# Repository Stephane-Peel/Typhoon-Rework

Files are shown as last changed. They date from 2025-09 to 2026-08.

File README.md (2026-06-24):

# Typhoon
Clouds variant

Fork to share production files used to make mine.

- Frontpanel rework to my taste.
- Kicad conversion from Diptrace
- 3D CAD : Fusion 360 & STL
- Original Fuzzy BOM reference completed

Beware : 
--------
The current files where used for my build.
It should be ok, but please double check everything to make your own module ;)

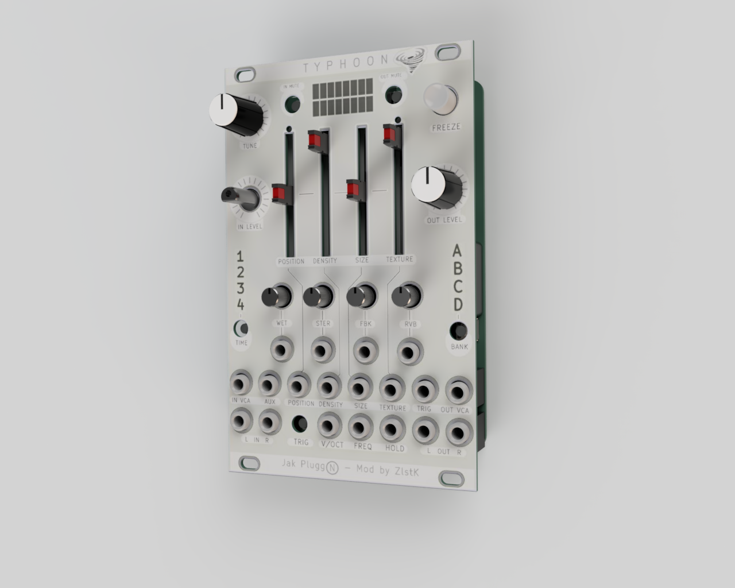
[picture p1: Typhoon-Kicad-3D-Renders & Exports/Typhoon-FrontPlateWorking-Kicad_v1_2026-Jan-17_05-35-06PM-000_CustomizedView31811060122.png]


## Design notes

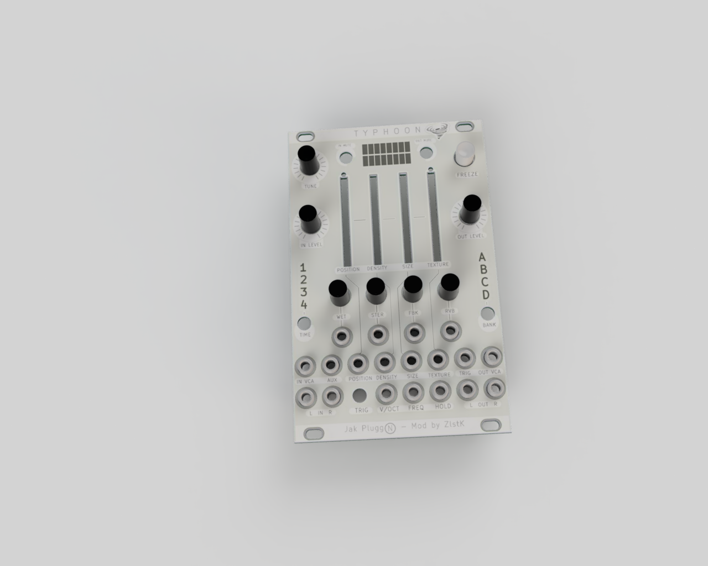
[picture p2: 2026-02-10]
Typhoon-Kicad-3D-Renders & Exports/33a217c0-9740-4eda-9ab5-972cdd618269.PNG

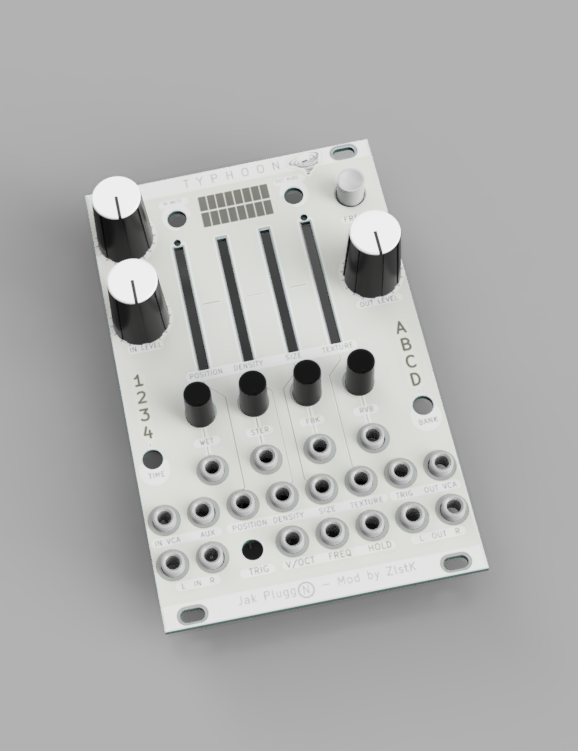
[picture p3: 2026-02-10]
Typhoon-Kicad-3D-Renders & Exports/Typhoon-FrontPlateWorking-Kicad_v1_2026-Jan-16_11-33-02PM-000_CustomizedView1730624913.png

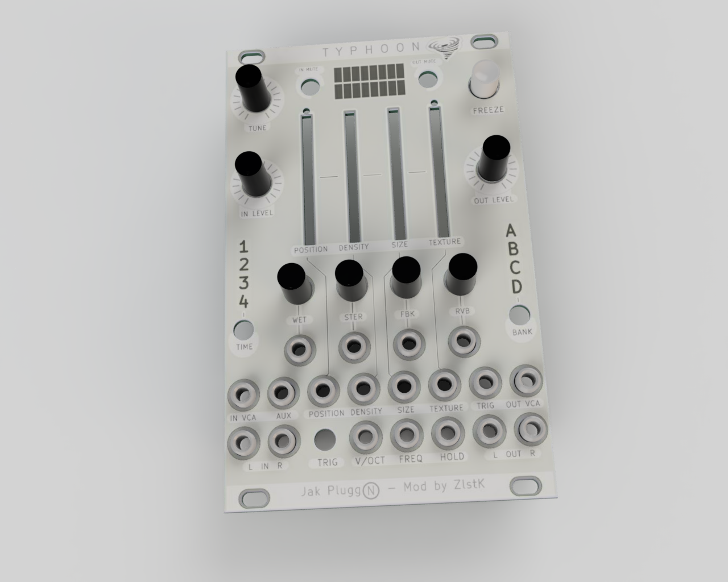
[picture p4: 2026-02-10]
Typhoon-Kicad-3D-Renders & Exports/Typhoon-FrontPlateWorking-Kicad_v1_2026-Jan-16_11-52-13PM-000_CustomizedView21636484477.png

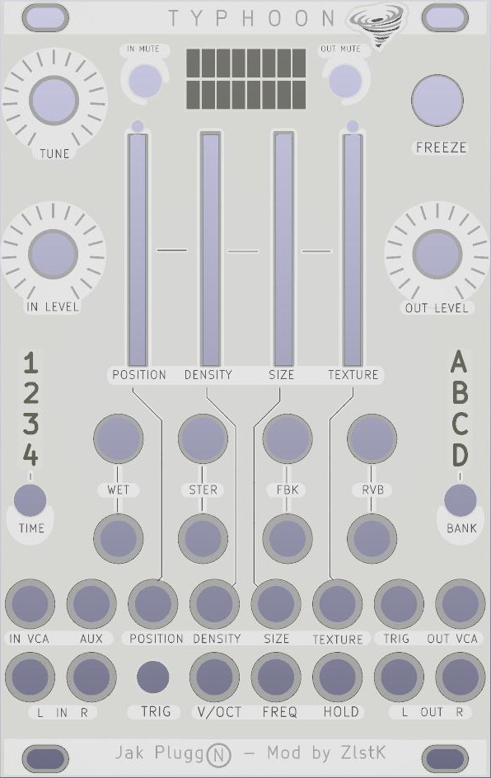
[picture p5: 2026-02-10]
Typhoon-Kicad-3D-Renders & Exports/Typhoon-Frontpanel-LargeKnobs.jpg

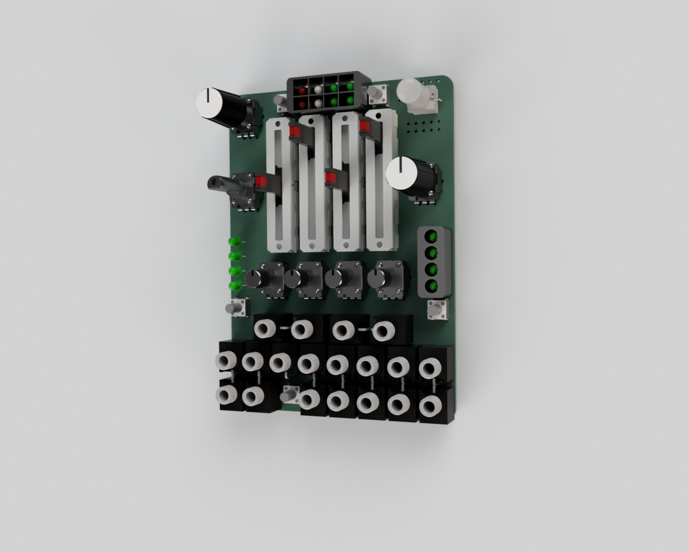
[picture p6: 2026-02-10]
Typhoon-Kicad-3D-Renders & Exports/Typhoon-FrontPlateWorking-Kicad_v1_2026-Jan-17_05-37-42PM-000_CustomizedView23703180181.png

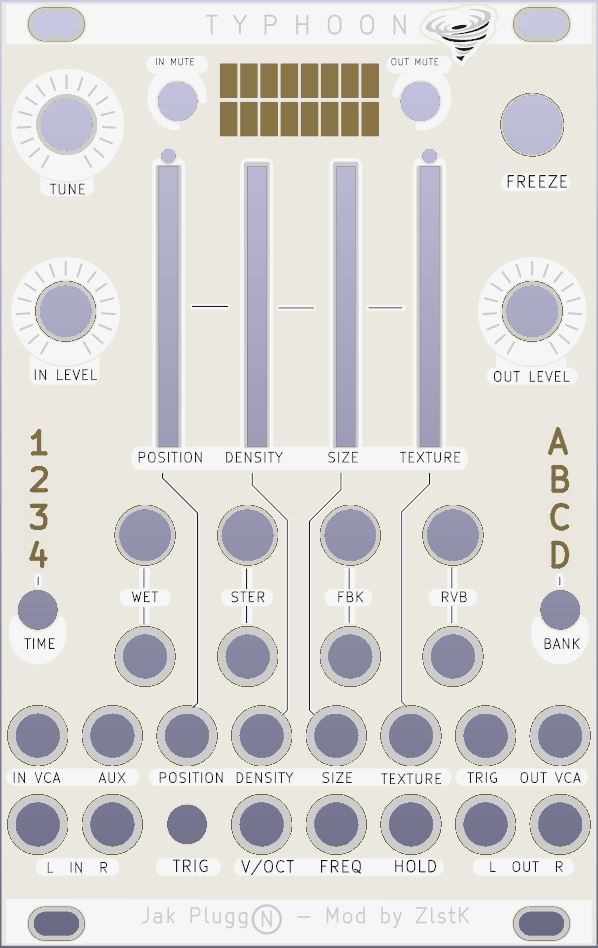
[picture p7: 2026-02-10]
Typhoon-Kicad-3D-Renders & Exports/FrontplateV1.1.JPG

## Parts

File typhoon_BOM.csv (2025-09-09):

Quantity | Value | Name | RefDes
2 | 2.2UF | C-EUC0603 (C-EU) | C1, C8
4 | 18PF | C-EUC0603 (C-EU) | C2, C3, C42, C43
7 | 10UF | C-EU-POL_4D (C-EU-POL) | C4, C17, C19, C20, C28, C29, C30
33 | 100NF | C-EUC0603 (C-EU) | C5, C6, C7, C11, C13, C15, C16, C18, C21, C22, C23, C26, C31, C32, C33, C37, C40, C44, C48, C51, C53, C55, C56, C61, C62, C63, C66, C70, C71, C72, C73, C75, C78
6 | 47PF | C-EUC0603 (C-EU) | C9, C12, C24, C25, C64, C65
2 | 220PF | C-EUC0603 (C-EU) | C10, C14
4 | 10UF | C-EUC0805 (C-EU) | C27, C35, C36, C50
8 | 560PF | C-EUC0603 (C-EU) | C34, C39, C45, C46, C47, C49, C52, C54
2 | 470NF | C-EUC0603 (C-EU) | C38, C41
9 | 10NF | C-EUC0603 (C-EU) | C57, C58, C59, C60, C67, C68, C69, C74, C76
1 | 1NF | C-EUC0603 (C-EU) | C77
1 |  | MB1S | D1
2 | FB | FERRITE_BEAD_0603 (FERRITE_BEAD) | FB1, FB2
3 | Eurorack Jack | EURO_JACKS_SMALL_SILK (EURO_JACK) | J_AUX, J_HOLD, J_TRIG
16 | Eurorack Jack | EURO_JACKS_SILK (EURO_JACK) | J_DENS, J_FDBK, J_I-LVL, J_LIN, J_LOUT, J_MIX, J_O-LVL, J_PAN, J_PITCH, J_POSI, J_RIN, J_ROUT, J_SIZE, J_TEXT, J_VERB, J_VOCT
1 |  | M04PTH | JP1
10 | 2mm Yellow Diffused | LED_SILK (LED) | LED_A, LED_B, LED_C, LED_D, LED_IN3, LED_OUT3, LED_T1, LED_T2, LED_T3, LED_T4
4 | 2mm Green Diffused | LED_SILK (LED) | LED_IN1, LED_IN2, LED_OUT1, LED_OUT2
2 | 2mm Red Diffused | LED_SILK (LED) | LED_IN4, LED_OUT4
1 | M05X2PTH | M05X2PTH | P1
1 | Mini JTAG Header | M05X2MINIJTAG (M05X2) | P2
1 | 12.288MHz | TXC 7A crystal | Q1
1 | 8MHz | TXC 7A crystal | Q2
2 | MMBT3904 | -NPN-MMBT3904LT1SOT23-BEC (*-NPN-) | Q3, Q4
5 | 100R | R-US_R0603 (R-US_) | R1, R2, R7, R8, R75
18 | 1K | R-US_R0603 (R-US_) | R3, R4, R5, R6, R39, R42, R44, R46, R47, R48, R49, R50, R90, R91, R98, R99, R100, R101
2 | 2K | R-US_R0603 (R-US_) | R9, R11
6 | 10K | R-US_R0603 (R-US_) | R10, R13, R14, R16, R17, R21
2 | 5K1 | R-US_R0603 (R-US_) | R12, R15
5 | 22K | R-US_R0603 (R-US_) | R18, R20, R29, R30, R34
10 | 510R | R-US_R0603 (R-US_) | R19, R22, R23, R26, R27, R32, R33, R35, R37, R67
3 | 1M | R-US_R0603 (R-US_) | R24, R41, R71
2 | 39K | R-US_R0603 (R-US_) | R25, R31
2 | 49K9 | R-US_R0603 (R-US_) | R28, R36
23 | 100K | R-US_R0603 (R-US_) | R38, R40, R43, R45, R51, R52, R61, R62, R63, R64, R65, R66, R68, R70, R73, R74, R82, R86, R87, R92, R93, R95, R97
12 | 200K | R-US_R0603 (R-US_) | R53, R55, R56, R57, R69, R72, R76, R77, R78, R83, R85, R94
9 | 33K | R-US_R0603 (R-US_) | R54, R58, R59, R60, R79, R80, R81, R84, R88
1 | 180K | R-US_R0603 (R-US_) | R89
1 | 47K | R-US_R0603 (R-US_) | R96
5 | Mini Button | TAC_SWITCHTACTILE_PTH_SILK (TAC_SWITCH) | S_BANK, S_MUTE_INS, S_MUTE_OUTS, S_TIME, S_TRIG
1 | LED Button White | LED_BUTTONLED_BUTTON_SILK (LED_BUTTON) | S_HOLD
1 | STM32F427VIT6 | STM32F4XXV2 | U1
1 |  | WM8731 | U2
2 | TL074 | TL074_SO-14 (TL074) | U3, U16
2 | LD1117-3V3 | LD1117-3V3 (LD1117) | U4, U10
2 | 2164 | SSI2164 | U5, U9
1 | LM4040-2V5 | LM4041DBZA12 (LM4041) | U6
2 | LM4040-10V | LM4041DBZA12 (LM4041) | U7, U13
1 | 4051 | 4051_MUX | U8
5 |  | MCP6002 | U11, U12, U15, U17, U18
1 | TL072 | TL072_SO-8 (TL072) | U14
2 |  | TLE2172 | U19, U20
4 |  | bourns PTL LED slide pot | VR_DENS, VR_POSI, VR_SIZE, VR_TEXT
7 | P-10K-B | POT_9MM_SNAP-IN__ (POT_9MM_SNAP-IN_) | VR_FDBK, VR_IN, VR_MIX, VR_OUT, VR_PAN, VR_PITCH, VR_VERB

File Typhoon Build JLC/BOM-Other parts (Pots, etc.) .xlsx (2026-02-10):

Comment | Designator | Ref. | Quantity | Comment
Eurorack Jack | J_DENS, J_FDBK, J_I-LVL, J_LIN, J_LOUT, J_MIX, J_O-LVL, J_PAN, J_PITCH, J_POSI, J_RIN, J_ROUT, J_SIZE, J_TEXT, J_VERB, J_VOCT, J_AUX, J_HOLD, J_TRIG | Thonkiconn | 19 | Thonk : ok Ali : ok
Mini Button | S_BANK, S_MUTE_INS, S_MUTE_OUTS, S_TIME, S_TRIG | E-Switch - 1RLGR (depend on your choice) | 5 | Digikey : ok | https://www.digikey.fr/fr/products/detail/e-switch/1RLGR/271580
Tactile Switch |  | E-Switch - TL1105SPF160Q | 5 | Digikey : ok | https://www.digikey.fr/fr/products/detail/e-switch/TL1105SPF160Q/271558
LED Button White | S_HOLD | E-Switch - LP4OA1PBCTG | 1 | Banzai : ok Ali : ok | https://www.digikey.fr/fr/products/detail/e-switch/LP4OA1PBCTG/1984647
WM8731 | U2 |  |  | Ali : ok
AS2164 | U5, U9 | SO-16 | 2 | Exploding : ok Banzai : ok Thonk : x3 uniquement
 | VR_DENS, VR_POSI, VR_SIZE, VR_TEXT | Bourns - PTL30-10G1-103B2 | 4 | Digikey : ok | https://www.digikey.fr/fr/products/detail/bourns-inc/PTL30-10G1-103B2/4699464
P-10K-B | VR_FDBK, VR_IN, VR_MIX, VR_OUT, VR_PAN, VR_PITCH, VR_VERB | Alps - RK09K1130A5R | 4 | Digikey : ok | https://www.digikey.fr/fr/products/detail/alps-alpine/RK09K1130A5R/21721633
B10K |  | Alps - RK09D1130C2P | 3 | Digikey : ok | https://www.digikey.fr/fr/products/detail/alps-alpine/RK09D1130C2P/19529056
Led Slider | Bicolor LEDs for PTL30 | Bivar - R3BC | 4 | Digikey : ok | https://www.digikey.fr/fr/products/detail/bivar-inc/R3BC/3101096
Front-Panel Screw | 2,5mm x10 |  | 2
Pot Caps | Pots Caps |  | 3

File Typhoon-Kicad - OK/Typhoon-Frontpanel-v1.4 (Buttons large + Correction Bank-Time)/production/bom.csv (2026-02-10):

Designator | Footprint | Quantity | Value | LCSC Part #
PAD1, PAD15, PAD16, PAD17, PAD18, PAD19, PAD2, PAD20, PAD3, PAD30, PAD31, PAD32, PAD33, PAD4, PAD5, PAD6, PAD7, PAD8, PAD9 | RES_0805_Pad1 | 19 | PAD
PAD10, PAD11, PAD13, PAD14 | Pad-Eurorack-Vis | 4 | PAD
PAD12 | RES_0805_Pad12 | 1 | PAD
PAD21, PAD22, PAD23, PAD24, PAD25, PAD26, PAD34 | RES_0805_Pad21 | 7 | PAD
UNK_HOLE_0 | dummyfp0 | 1
UNK_HOLE_1 | dummyfp1 | 1
UNK_HOLE_2 | dummyfp2 | 1
UNK_HOLE_3 | dummyfp3 | 1
UNK_HOLE_4 | dummyfp4 | 1
UNK_HOLE_5 | dummyfp5 | 1
UNK_HOLE_6 | dummyfp6 | 1

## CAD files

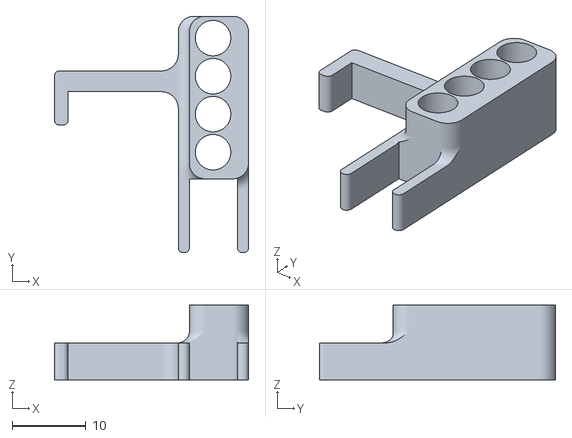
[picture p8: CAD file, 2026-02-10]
Typhoon - CAD Files/TyphoonGuide1234.stl
26.3 x 32.0 x 10.1

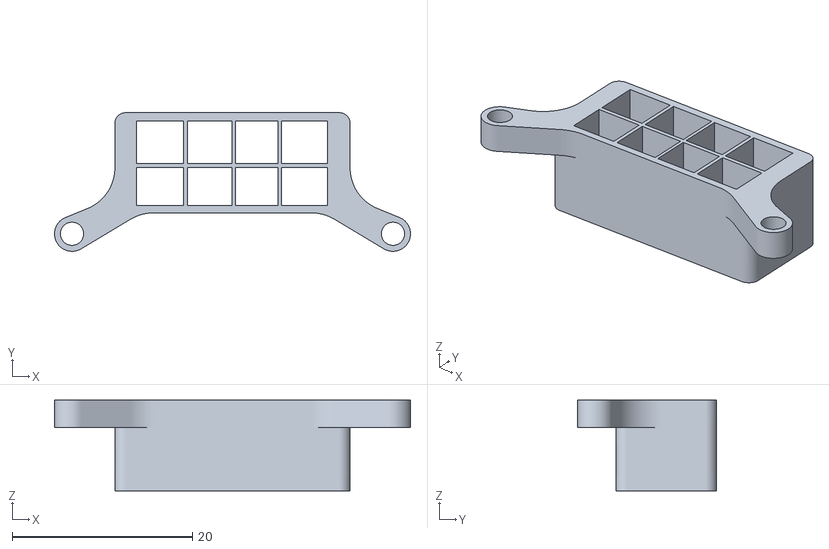
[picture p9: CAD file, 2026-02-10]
Typhoon - CAD Files/TyphoonGuideVueMeter.stl
39.5 x 15.4 x 10.1

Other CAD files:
Typhoon - CAD Files/TyphoonGuideABCD.stl
Typhoon - CAD Files/Typhoon-FrontPlateWorking-Kicad.f3z

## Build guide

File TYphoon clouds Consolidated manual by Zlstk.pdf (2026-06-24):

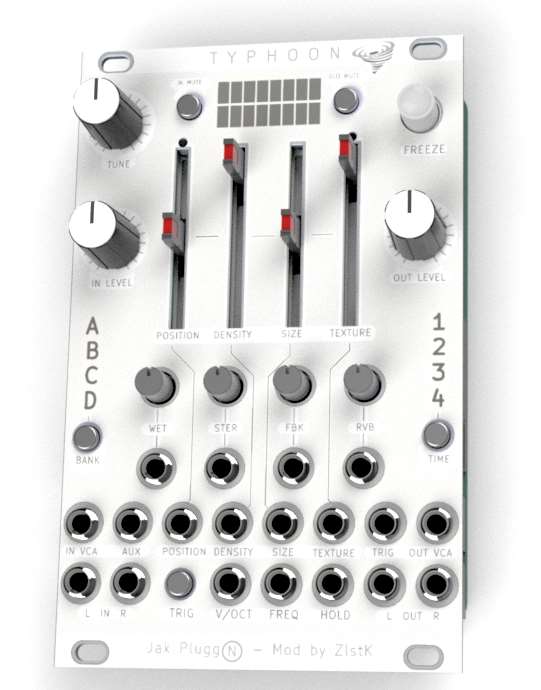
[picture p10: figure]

# TYphoon - Clouds

# Superparasite

# Consolidated Manual V 1.0

Typhoon Clouds – Superparasite Consolidated Manual V1.0 – By Zlstk

# Overview

This Document is a compilation of the documentation of these differents version of Clouds and the work of other people:

Original Clouds by Emilie Gillet : https://pichenettes.github.io/mutable-instruments-documentation/modules/clouds/manual/# (https://pichenettes.github.io/mutable-instruments-documentation/modules/clouds/manual/)

Supercell : https://grayscale.info/supercell/

Microcell : https://microcell.cc/

Capital-G : https://github.com/capital-G/typhoon-manual

Clouds is a granular audio processor. It creates textures and soundscapes by combining multiple overlapping, delayed, transposed and enveloped segments of sound taken from an audio recording buffer.

Clouds differs from other granular Eurorack modules in that it focuses on the real-time processing of audio sources from your modular system itself, rather than the playback of pre-recorded samples from a storage device. It rewards the freezing, fragmentation and dissolution of the unexpected instant, rather than the careful planning of what might very well not come.

(Source – Original Clouds Manual by Emilie Gillet)

Typhoon is an iteration of differents versions of the original Clouds module by Emilie Gillet.

Clouds ->Supercell -> Microcell Clouds -> µBurst -> Moonsoon -> TYPHOON

Typhoon offer extra controls and mods comparing to original Clouds.
It use the Superparasite firmware. (see https://github.com/patrickdowling/superparasites for more details).

Superparasite include all the regular Clouds modes, all the Parasites modes, and Kammerl Beat Repeat and Spectral Clouds modes.

Mode 1 [●○○○]: Granular Clouds (Parasites)
Mode 2 [○●○○]: Pitch Shift / Time Stretch (Parasites) Mode 3 [○○●○]: Looping Delay (Parasites)
Mode 4 [○○○●]: Spectral Processor (Parasites)
Mode 5 [○●●●]: Oliverb (Parasites)
Mode 6 [●○●●]: Resonestor (Parasites)
Mode 7 [●●○●]: Beat Repeat (Kammerl)
Mode 8 [●●●○]: Spectral Clouds (Kammerl)

# General Settings and functionnality

Microcell - Calibration Procedure:

1. Patch a cable from any DC offset source or MIDI-to-CV module into the V/OCT input (not the Pitch input).
2. Power on your modular system while holding the TRIG switch. The input VU meter will start to blink.
3. Send a 1V DC offset into the module. Many Eurorack modules can generate DC offsets but you will need some way to measure the voltage. Use a digital multimeter or an oscilloscope module like the Mordax DATA to generate precise values. Alternately, use your MIDI-to-CV module and play a C2 note. When the 1V signal is present at the V/OCT input, press the TRIG switch.
4. The output VU meter will now start to blink. Change the 1V DC offset to 3V instead (or play C4 on your MIDI-to-CV module), then press the TRIG switch once more. The calibration process will exit and the module will return to normal operation.

Supercell - Exponential and Linear Pitch Control

The PITCH parameter is now controlled by two separate CV inputs.
The V/OCT input is exponential and the Pitch input is linear (with an attenuverter). When both inputs are used, the two voltages are summed.

Supercell - Trigger Switch

Clouds had a trigger/gate input for generating individual grains.
Supercell adds a manual TRIG switch that performs the same function.
It’s particularly useful with some of the alternate firmware modes such as Beat Repeat.
This switch isalso used for the quick reload function and adjustment of the internal random voltage generator’s clock rate. See the notes above for details

Supercell - Expanded Modulation Options

Each of the nine granular processing parameters has its own CV input with an inverting attenuator (attenuverter) to set the level and polarity of external CVs.

Along with patching external CVs directly to each CV input, you may want one CV to affect multiple parameters without using splitter cables or a multiple module. Patch a CV signal into AUX and it will be distributed to all nine of the parameters.

The attenuverters can still be used to control the modulation depth of this distributed CV signal. Patching a different signal directly into one of the nine CV inputs will disconnect the AUX signal from that parameter.

Supercell - Internal Modulation

There is a third option for modulation, which involves a fluctuating random CV that is internally generated by the module itself. Any unpatched parameter inputs will receive this signal automatically (assuming that the AUX input is also unpatched, because patching into AUX overrides this internal random CV). The attenuverters control the modulation depth here as well.
> To prevent the internal modulation from changing a parameter, set the attenuator to its center position. > To change the frequency of the random CV changes. Press and hold the TRIG switch and then turn the PAN knob until the HOLD LED starts to blink. The randomization frequency will change when the TRIG switch hold is released. Return the Pan knob to its original position if needed.
>The available range is from 1 Hz to 100 Hz.
> To disable the internal random CV, press both of the mute switches for about two seconds. > When the modulation, is activated you can see a visual activity on the four slider pots of Typhoon

Microcell - attenuation feature :

- Press and hold the TIME switch, then turn a knob within 3 seconds (otherwise you enter the mode selection UI).
The knob now functions as an attenuator for that parameter's CV input.
The attenuation value is saved when you release the TIME switch hold.
Turning other knobs before releasing the switch hold will adjust their attenuation values too.
- Press and hold the BANK switch, then turn a knob within 3 seconds (otherwise you enter the preset saving UI).
This works as described above, but the knob functions an inverting attenuator.
With the knob turned to left of center incoming CVs with be attenuated *and* inverted, while values to the right of center will only be attenuated.
This function works for all nine of the DSP parameters.
It does not work for the analog Input and Output VCAs.

It does however mean that the internal randomization feature can be used more effectively.

Just enable the randomization (press and hold the In and Out mute switches for 5 seconds), then set the attenuation values.

Stereo Input/Output VCAs

The inputs and outputs now include stereo VCAs and separate VU meters. The knobs for Input and Output function as DC offsets for their respective VCAs, setting the modulation baseline when the VCA inputs are patched, so turn these knobs to their minima if you want to use unipolar CV sources like envelopes. CV signals affect the left and right channels equally. If you prefer to modulate the left and right channels separately, this can be accomplished with external VCAs.

# License

cc-by-sa 3.0

Mutable Instruments Manual: cc-by-sa 3.0

Kammerl: MIT License (https://www.kammerl.de/audio/clouds/NOTICE.txt)

Parasites: MIT LIcense (https://mqtthiqs.github.io/parasites/)

Superparasites: MIT License (https://github.com/patrickdowling/superparasites#license)

# Mode 1 [●○○○]: Granular Clouds (Parasites)

Source: mqtthiqs Parasites (https://mqtthiqs.github.io/parasites/clouds.html)

ORIGINAL
BUTTON

PARAMETER DESCRIPTION

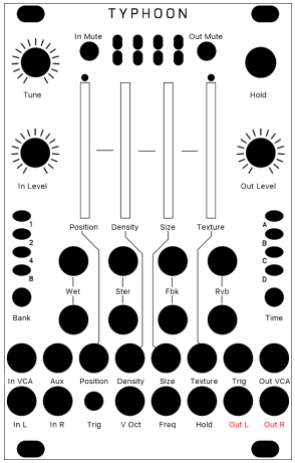
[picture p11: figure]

POSITION | Position | Selects from which part of the recording buffer the audio grains are
| | played. Turn the knob clockwise to travel back in time.
DENSITY | Density | At 12 o’clock, no grains are generated. Turn clockwise and grains will be
| | sown randomly, counter-clockwise and they will be played at a constant
| | rate. The further you turn, the higher the overlap between grains.
SIZE | Size | At 12 o’clock, the buffer is played at its original frequency.
TEXTURE | Texture | Morphs through various shapes of grain envelopes: square (boxcar),
| | triangle, and then Hann window. Past 2 o’clock, activates a diffuser which
| | smears transients.
WET | Wet | Dry/wet balance
STEREO | Stereo | Stereo spread (amount of random panning/balance applied to the grains).
FEEDBACK | Feedback | Feedback amount.
REVERB | Reverb | Reverberation amount.
FREEZE | Freeze | This latching button stops the recording of incoming audio.
| | Granularization is now performed on the last few seconds of audio kept
| | in memory in the module. When the input gate signal is high, stops the
| | recording of incoming audio, just as latching the FREEZE button would
| | do.
TRIGGER | Trigger | Generates a single grain. By moving the grain DENSITY to 12 o’clock, and
| | sending a trigger to this input, Clouds can be controlled like a micro-
| | sample player. An LFO or clock divider (or even a pressure plate) can thus
| | be used to sow grains at the rate of your choice.
INPUT LEVEL | In Level | From -18dB to +6dB.

# Mode 2 [○●○○]: Pitch Shift / Time Stretch (Parasites)

This mode is quite similar to the granular mode, except that it uses two overlapping grains synchronized with the most salient period of the sound. The grains are carefully spliced so that they mesh well with each other (a technique similar to the “deglitching” of early pitch-shifters).

Source: mqtthiqs Parasites (https://mqtthiqs.github.io/parasites/clouds.html)

ORIGINAL
BUTTON

PARAMETER DESCRIPTION

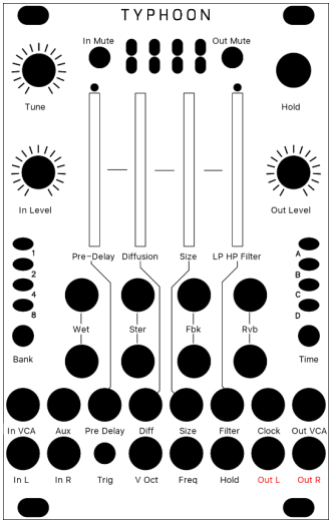
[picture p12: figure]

POSITION | Pre-Delay | Modulating POSITION when recording is frozen will “scrub” through the audio buffer. Clouds’ uses classic time-domain methods which are not suitable for polyphonic or percussive material (unless this percussive material is breakbeats and you liked Akai samplers. Then: smile).
DENSITY | Diffusion | Creates a granular diffusion effect based on all-pass filters.
SIZE | Size | Controls the size of the overlapping windows used for pitch-shifting and time-stretching – from an extremely grainy “drilling” sound to smooth bits of loops.
TEXTURE | LP/HP Filter | Acts as a low-pass/high-pass filter.
TRIGGER | Trigger | Sending a trigger to the TRIG input creates a clock-synchronized loop (when FREEZE is enabled) or stuttering effect – equivalent to applying a tempo-synchronized decaying envelope on the POSITION parameter.

# Mode 3 [○○●○]: Looping Delay (Parasites)

The looping delay mode continuously plays back audio from the buffer without any kind of granularization.

Source: mqtthiqs Parasites (https://mqtthiqs.github.io/parasites/clouds.html)

ORIGINAL
BUTTON

PARAMETER DESCRIPTION

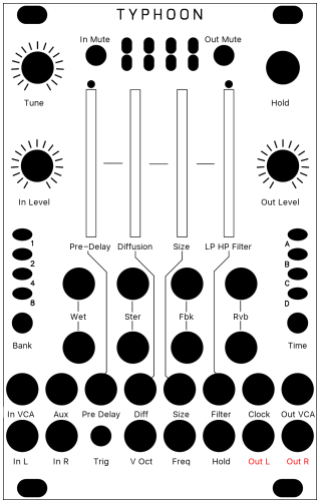
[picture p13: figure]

POSITION | Pre-Delay | Controls the distance between the playback head and the recording head (in other words, the delay time). Modulating POSITION will create effects similar to vinyl scratching or manual manipulation of tape.
DENSITY | Diffusion | Creates a granular diffusion effect based on all-pass filters.
SIZE | Size | Controls the size of the overlapping windows used for pitch-shifting and time-stretching – from an extremely grainy “drilling” sound to smooth bits of loops.
TEXTURE | LP/HP Filter | Acts as a low-pass/high-pass filter.
HOLD | Hold | When FREEZE is activated, the content of the audio buffer is looped (stutter effect). POSITION controls the loop start and SIZE the loop duration. DENSITY creates a granular diffusion effect based on all-pass filters; and TEXTURE acts as a low-pass/high-pass filter.

# Mode 4 [○○○●]: Spectral Processor (Parasites)

In this mode, the incoming signal is converted into “frames” of spectral data, that are stored, transformed, recombined, and resynthesized as a time-domain signal.

Source: mqtthiqs Parasites (https://mqtthiqs.github.io/parasites/clouds.html)

ORIGINAL
BUTTON
| PARAMETER | DESCRIPTION

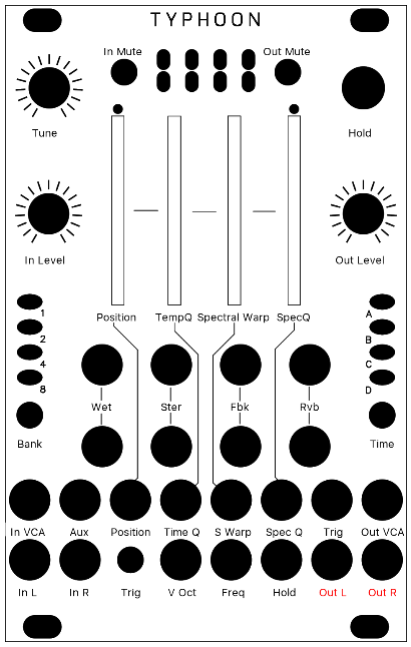
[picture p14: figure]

POSITION | Position | POSITION selects into which buffer the audio is poured (when FREEZE is not active), or from which buffer the audio is synthesised (when FREEZE is active). For example, set POSITION to its minimum value. Press FREEZE. You get a first texture. Set POSITION to its maximum value. UNFREEZE. Wait for something else to happen in the incoming audio. Press FREEZE again. By moving POSITION you interpolate between the two textures which had been captured at the press of FREEZE. Depending on the quality settings there are 2 to 7 buffers laid out over the course of the POSITION knob. What the module does is crossfade between a “wavetable” of FFT slices.
DENSITY | Tempo Quantisation | Determines how results from the analyzer are passed to the resynthesizer. Below 12 o’clock, there’s some increasing probability that a given FFT bin won’t get updated, causing a kind of partial freeze. After 12 o’clock, adjacent analysis frames are increasingly merged together (like a low-pass filter in the amplitude each frequency bin). At extreme settings, random phase modulation is applied to smooth things - giving you different flavours of spectral muddling/reverb.
SIZE | Spectral Warp | Changes the coefficients of a polynomial that determines how frequencies are mapped between the analysis and synthesis buffers. It’s like a 1-knob GRM Warp. Over the course of the knob it’ll do spectral shifting, but also spectral reversal.
TEXTURE | Spectral Quantisation | Does two things: below 12 o’clock, it increasingly quantizes the amplitudes of the spectral components, like a very low-bitrate audio file. After 12 o’clock, it increasingly weakens the strongest partials and amplifies the weakest ones. This has the effect of making the spectrum more noise-like.
TRIGGER | Trigger | Sending a trigger to the TRIG input creates various frequency-domain glitches typical of corrupted (encoded) audio files. It works as a kind of build-up/feedback effect - the shorter the pulse, the smaller the effect. With a continuous gate, it’ll really start to rot…

# Mode 5 [○●●●]: Oliverb (Parasites)

A new, full-featured creative reverb mode based on the reverb of the original firmware (itself based on a description of the Lexicon 480L), and inspired in design by the Erbe Verb, with CV control over all parameters. It is largely modeless, probably unrealistic and goes far beyond your traditional reverb

Source: mqtthiqs Parasites (https://mqtthiqs.github.io/parasites/clouds.html)

ORIGINAL
BUTTON
| PARAMETER | DESCRIPTION

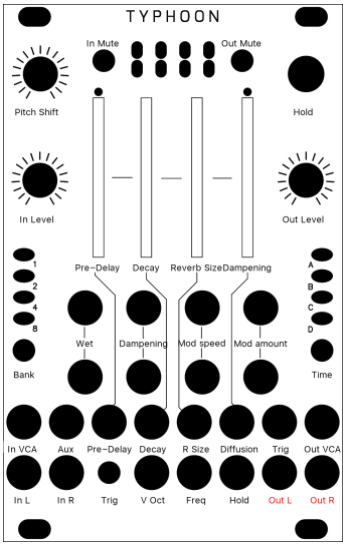
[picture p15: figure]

POSITION | Pre-Delay | The Position knob controls the time it take for the reverb to kick in after a sound has gone in (from 0 to about half a second). When a clock is fed to the Trig input, this knob becomes a clock divider/multiplier for the pre-delay: at 12 o'clock, the pre-delay takes the value of the clock length; clockwise, this clock is divided, and counter-clockwise it is multiplied following the rates: 1/16, 3/32, 1/8, 3/16, 1/4, 3/8, 1/2, 3/4, 1, 3/2, 2/1, 3/1, 4/1, 6/1, 8/1, 12/1 (borrowed from the Echophon). Note that the clock division is limited to the largest division not exceeding the maximum delay; beyond this point, the Position knob will have no effect. Changing pre-delay in real time is smooth and does not affect pitch (it uses the internal time stretcher).
DENSITY | Decay | The Density knob controls the amount of sound fed back into the reverb loop, i.e. the decay time of the reverb tail. Beyond 3 o'clock, this signal is actually amplified and the reverb enters self-oscillation.
SIZE | Reverb Size | The Size knob controls the lengths of all the delays internal to the reverb, i.e. the size of the emulated room. It varies from a small resonator to a huge hall.
TEXTURE | Dampening | The Texture knob controls the dampening of the reverb. From fully CCW to 12 o'clock, a low-pass filter is applied, simultaing the absorption of the room. From 12 o'clock to fully CW, a high-pass filter is applied for unusual, crystalline effects.

WET | Wet | The first function of the Blend knob is dry/wet crossfading, as in the other modes.
STEREO | Diffusion | The second Blend mode (called "stereo spread") controls how much the sound is "smoothened" by the diffusers each time it goes through the loop. Fully clockwise, you get the more dense, continuous sound; fully counter-clockwise, you clearly hear the sound being repeated like in a multi-tap delay.
FEEDBACK | Modulation | The third function of the Blend knob (called "feedback") controls the
| speed | speed of these LFOs. It ranges from ~1/100Hz to ~100Hz. It has no
effect if modulation amount is null.
REVERB | Modulation amount | Each delay in the reverb can be individually modulated by 9 smoothed random LFOs. The fourth function of the Blend knob (called "reverb") controls the amount of modulation applied by the LFOs to the delay time. Small modulations result in subtle chorus and ghost tones, large modulations in random pitch shifts.
TUNE | Pitch Shift | Each time the sound is fed back into the reverb, it can be pitch shifted. The Pitch knob controls, from -1 to +1 octaves how it is pitch shifted. At 12 o'clock, no pitch shifting is applied; fully clockwise, we get the classic shimmer effect; lots of oddities can be found in between. To hear the effect of the pitch shifter, some sound has to fed back by increasing Decay. Note that Size has an impact on how well the sound is pitch- shifted: the larger the room size, the more accurate the pitch shift.
FREEZE | Freeze | The Freeze button sets reverb to (near) infinite decay, and mutes the input. This works best with no pitch shifting and a large size.

# Mode 6 [●○●●]: Resonestor (Parasites)

It is a dual-voice, four-parts resonator (or comb filter) effect with built-in capability for polyphonic Karplus-Strong plucked string synthesis, and more. You access it by long-pressing the Blend button until LEDs become orange, and press it again several times until only the second LED is unlit (in other words, if LEDs 1, 3 and 4 are lit).

Source: mqtthiqs Parasites (https://mqtthiqs.github.io/parasites/clouds.html)

ORIGINAL
BUTTON
PARAMETER | DESCRIPTION

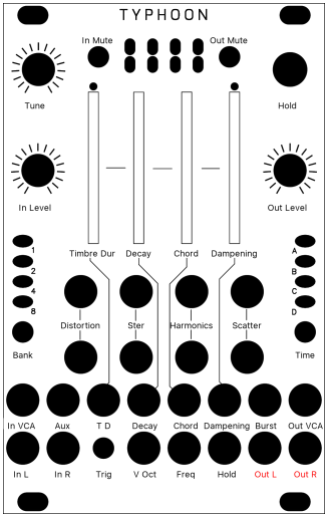
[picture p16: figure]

POSITION | Timbre | Controls the timbre and duration of the noise burst. CCW, it will be
| Duration | longer and more dampened; CW, it will be shorter and more high pitched.
At both ends of the knob, the burst will be inaudible (too damped or too short), which you can use to "mute" a voice.
DENSITY | Decay | Decay time of the current voice. Beyond approx. 3 o'clock, decay is infinite and the sound sustains forever (you can use it as a traditional oscillator).
SIZE | Chord | Chord selection for the current voice. Morphs gradually between Unison, Fat, Superfat, Fat power, Fat octave, Octaves, Power, Major, Major7, Minor7, Minor, Sus2, Sus4, Minor9, Major9, Minor11, Major11, and Major11.
TEXTURE | Dampening | Controls filtering in the feedback loop of the resonator. At 12 o'clock, no filtering is applied; CCW, a low-pass filter is applied with a increasingly low cutoff frequency; CW, a band-pass filter at the frequency of the resonator is applied with an increasingly high resonance.
WET | Distortion | Randomly distorts the timbre of the voices by modulating each comb filter by low pass-filtered noise. Fully CCW, the modulation amount is maximum but the noise is filtered out entirely, so there is no effect. Fully CW, the noise is unfiltered, but the modulation amount is null, so there is no effect. In between, you get interesting effects, from subtle swaying to harsh distortion.

STEREO | Stereo | Assigns each part and voice to an output (Out L or Out R). Fully CCW,
| | each voice goes to a different output. At 12 o'clock, both voices are
| | equally mixed in both output. Fully CW, parts of both voices are
| | distributed on both output for a wide stereo effect.
FEEDBACK | Harmonics | Simulates striking the harmonics on a string. Fully CCW, it has no effect.
| | Fully CW, the second harmonic will ring; at 12 o'clock, the third, at 10 the
| | fourth etc.
REVERB | Scatter | Controls the random delay times before the sound (input or burst) hits
| | each resonator of the current voice. Used for K-S synthesis with a chord,
| | this will give the impression that strings are struck sloppily. The delay
| | times are randomized at each voice switch.
TRIGGER | Burst | A trigger in this input will switch the current voice (if Freeze is not active)
| | and send a short burst of noise in its resonator.
HOLD | Hold | Switch the current voice, and inhibits further voice switch by the Trig CV.
TUNE | Pitch | Base pitch of the current voice. At 12 o'clock, the pitch is A3 (220Hz).

# Mode 7 [●●○●]: Beat Repeat (Kammerl)

Note: This mode requires a clock signal plugged into the Trigger input. Without a clock signal, it holds the most recent slice (or outputs silence if no clock signal has been previously provided).

The Kammerl Beat-Repeat mode analyzes the incoming clock signal to enable real-time slicing of the audio input. It manages multiple slices in real-time which can be individually selected. Each slice can be played back with different loop, pitch and distortion settings.

Source: Kammerl Clouds (https://www.kammerl.de/audio/clouds/)

ORIGINAL
BUTTON
| PARAMETER | DESCRIPTION

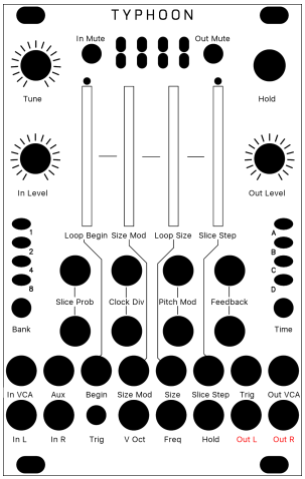
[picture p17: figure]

POSITION | Loop Begin | Defines the beginning of the loop interval relative to the total slice duration. To support in-sync beat repetitions, it is quantized as follows: [0-1/64] free/unquantized, 1/64, 1/32, 1/16, 1/8, 1/4, 1/3, 1/2, 1.
DENSITY | Loop Size Modulation | Enables a decreasing loop size towards the slice end. This enables a ping- pong bouncing ball effect: Tak tak tak taktak tatatatatttttttt
SIZE | Loop Size | Defines the size of the loop interval relative to the total slice duration as well as the loop mode (regular/alternating). To support in-sync beat repetitions, it is quantized as follows: Regular from the left to 12 o'clock: [0-1/64] free/unquantized, 1/64, 1/32, 1/16, 1/8, 1/4, 1/3, 1/2, Alternating from 12 o'clock to the right: 1/2, 1/3, 1/4, 1/8, 1/16, 1/32, 1/64, [1/64-0] free/unquantized
TEXTURE | Slice Step | The Texture CV and the Slice Step control different slice selection parameters. The Texture CV directly selects one of the most recently recorded slices. In contrast, the Slice Step parameter selects individual iteration patterns to jump between slices during playback (which also incorporates the Texture CV slice selection by using it as an offset) Disabled - Only Texture CV selects slices - Slice step 1 - Repeats current slice due to synced playback index - Slice step 2 - Skips every second slice - Slice step 3 - Skips two slices - Slice step 5 - Skips four slices - Slice step 6 - Skips five slices - Slice step 7 - Skips six slices - Random - Randomly selects slices. CV: Selects one of the eight most recently recorded slices. 0V corresponds to the most recent slice (real-time / no delay!). Note that slices are continously created from audio input, independent from FREEZE or slice probability mode.

WET | Slice | Defines the probability of disabling bypass and processing an incoming
| Probabillity | slice. Note that activating the FREEZE button overwrites this setting.
STEREO | Clock Divider | Selects a clock divider: 1, 1/2, 1/4, 1/8 which changes the slice lengths accordingly.
FEEDBACK | Pitch Mode | Selects one of four pitch modulation modes (from left to right): (left position) Fixed pitch - no modulation. Fixed pitch - reverse playback. Linearly decreasing pitch starting from the original pitch to the selected target pitch (Pitch Knob). Linearly increasing pitch starting from the the selected target pitch (Pitch Knob) to the original pitch. (right position) Simulated vinyl scratching - sinusoidal pitch modulation. The Pitch Knob defines the intensity.
REVERB | Feedback | Controls the contribution to Cloud's feedback path. Combined with lower pitch playback, this leads to amazing lazer gun effects on drums :)
TUNE | Pitch | Defines the playback speed. The Kammerl Beat-Repeat mode does not time-correct the pitch changes (like a tape or record running at different speeds). This allows for interesting groove effects, since audio is delayed towards the end of the slice but reset at the slice beginning. To the very left, the knob defines a zero pitch, to the very right, the original playback speed. The pitch modulation is determined by the Pitch Mode knob.
FREEZE | Freeze | Enables slice processing / beat-repeating. If not enabled, slice processing is randomly enabled based on the blend mode Slice Probability.

# Mode 8 [●●●○]: Spectral Clouds (Kammerl)

The Spectral Clouds mode creates cloud-like frequency spectras. It is a high-resolution multiband filter with randomly modulated frequency bands. The logarithmic divisions of the frequency spectrum result in a continuously morphing but musical sounding filter. This mode is inspired by this FFT Randomizer project.

Source: Kammerl Clouds (https://www.kammerl.de/audio/clouds/)

ORIGINAL
BUTTON
| PARAMETER | DESCRIPTION
POSITION | Frequency band

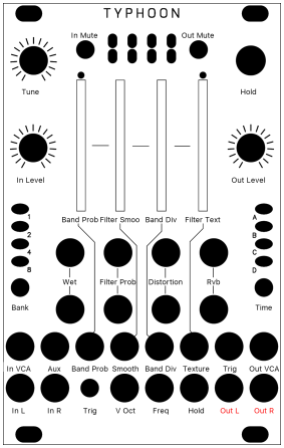
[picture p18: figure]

| probability | Defines the probability of a frequency band to become enabled. To
| | the left all frequency bands are disabled. Check out the sweet spot
| | where only a few frequency bands are active.
DENSITY | Filter Smoothing | Defines the smoothing intensity on the frequency band division as
| | well as the filter band attenuation changes during "trigger input"
| | events. To the left, filter changes are applied immediately; to the
| | right, the current filter configurations is hold.
SIZE | Frequency band
| division | Controls the number of filter bands and their corresponding
| | frequency width. To the left, the frequency spectrum is split into 4
| | filter bands and to the right into 128 filter bands. All frequency band
| | divisions are applied in logarithmic scale to sound musical.
TEXTURE | Filter texture | Defines the smoothing intensity on the frequency band division as
| | well as the filter band attenuation changes during "trigger input"
| | events. To the left, filter changes are applied immediately; to the
| | right, the current filter configurations is hold.
WET | Wet | Balance between input signal and Spectral Clouds output. Note that
| | the warm distortion effect as well as Cloud's reverb is applied post
| | dry / wet.
STEREO | Probability of
| random filter
| changes | Defines the chance of simulated "Trigger input" events. To the left,
| | simulated trigger events are disabled and random filter
| | reconfigurations only happen during high trigger input gates.
FEEDBACK | Warm distortion | It's back :) Adds a warm sounding distortion effect (applied post
| | dry/wet).
REVERB | Reverb | Controls the contribution to Cloud's reverb (applied post dry/wet).
TUNE | Pitch | Pitch shifting applied to the Spectral Clouds output.
TRIGGER | Trigger | Randomizes the set of active frequency bands and defines their
| | random attenuation intensity. Note that these trigger events can also
| | be simulated with the second blend mode ("Probability of random
| | filter changes").

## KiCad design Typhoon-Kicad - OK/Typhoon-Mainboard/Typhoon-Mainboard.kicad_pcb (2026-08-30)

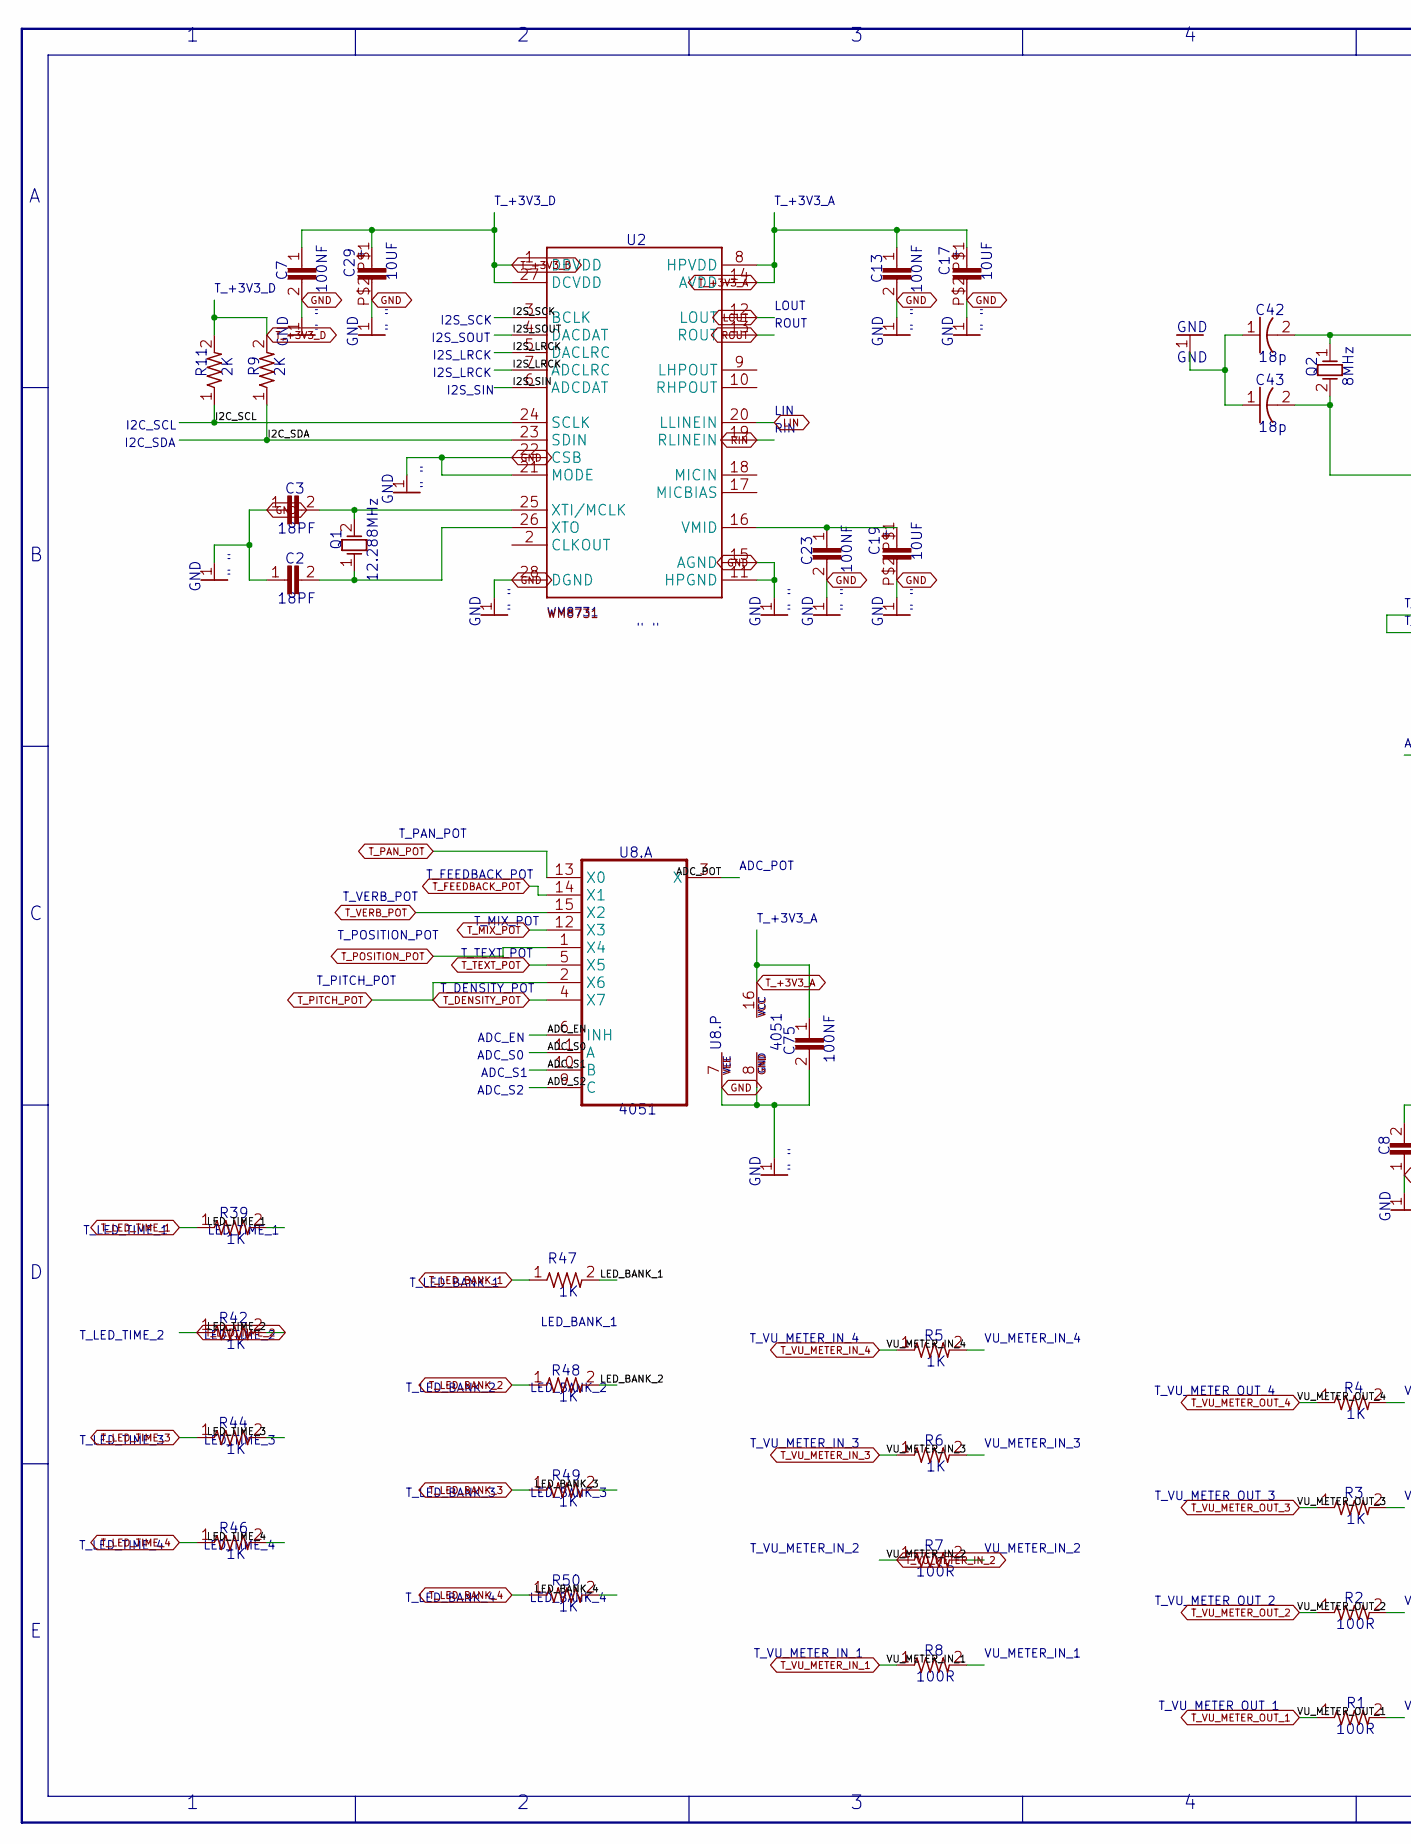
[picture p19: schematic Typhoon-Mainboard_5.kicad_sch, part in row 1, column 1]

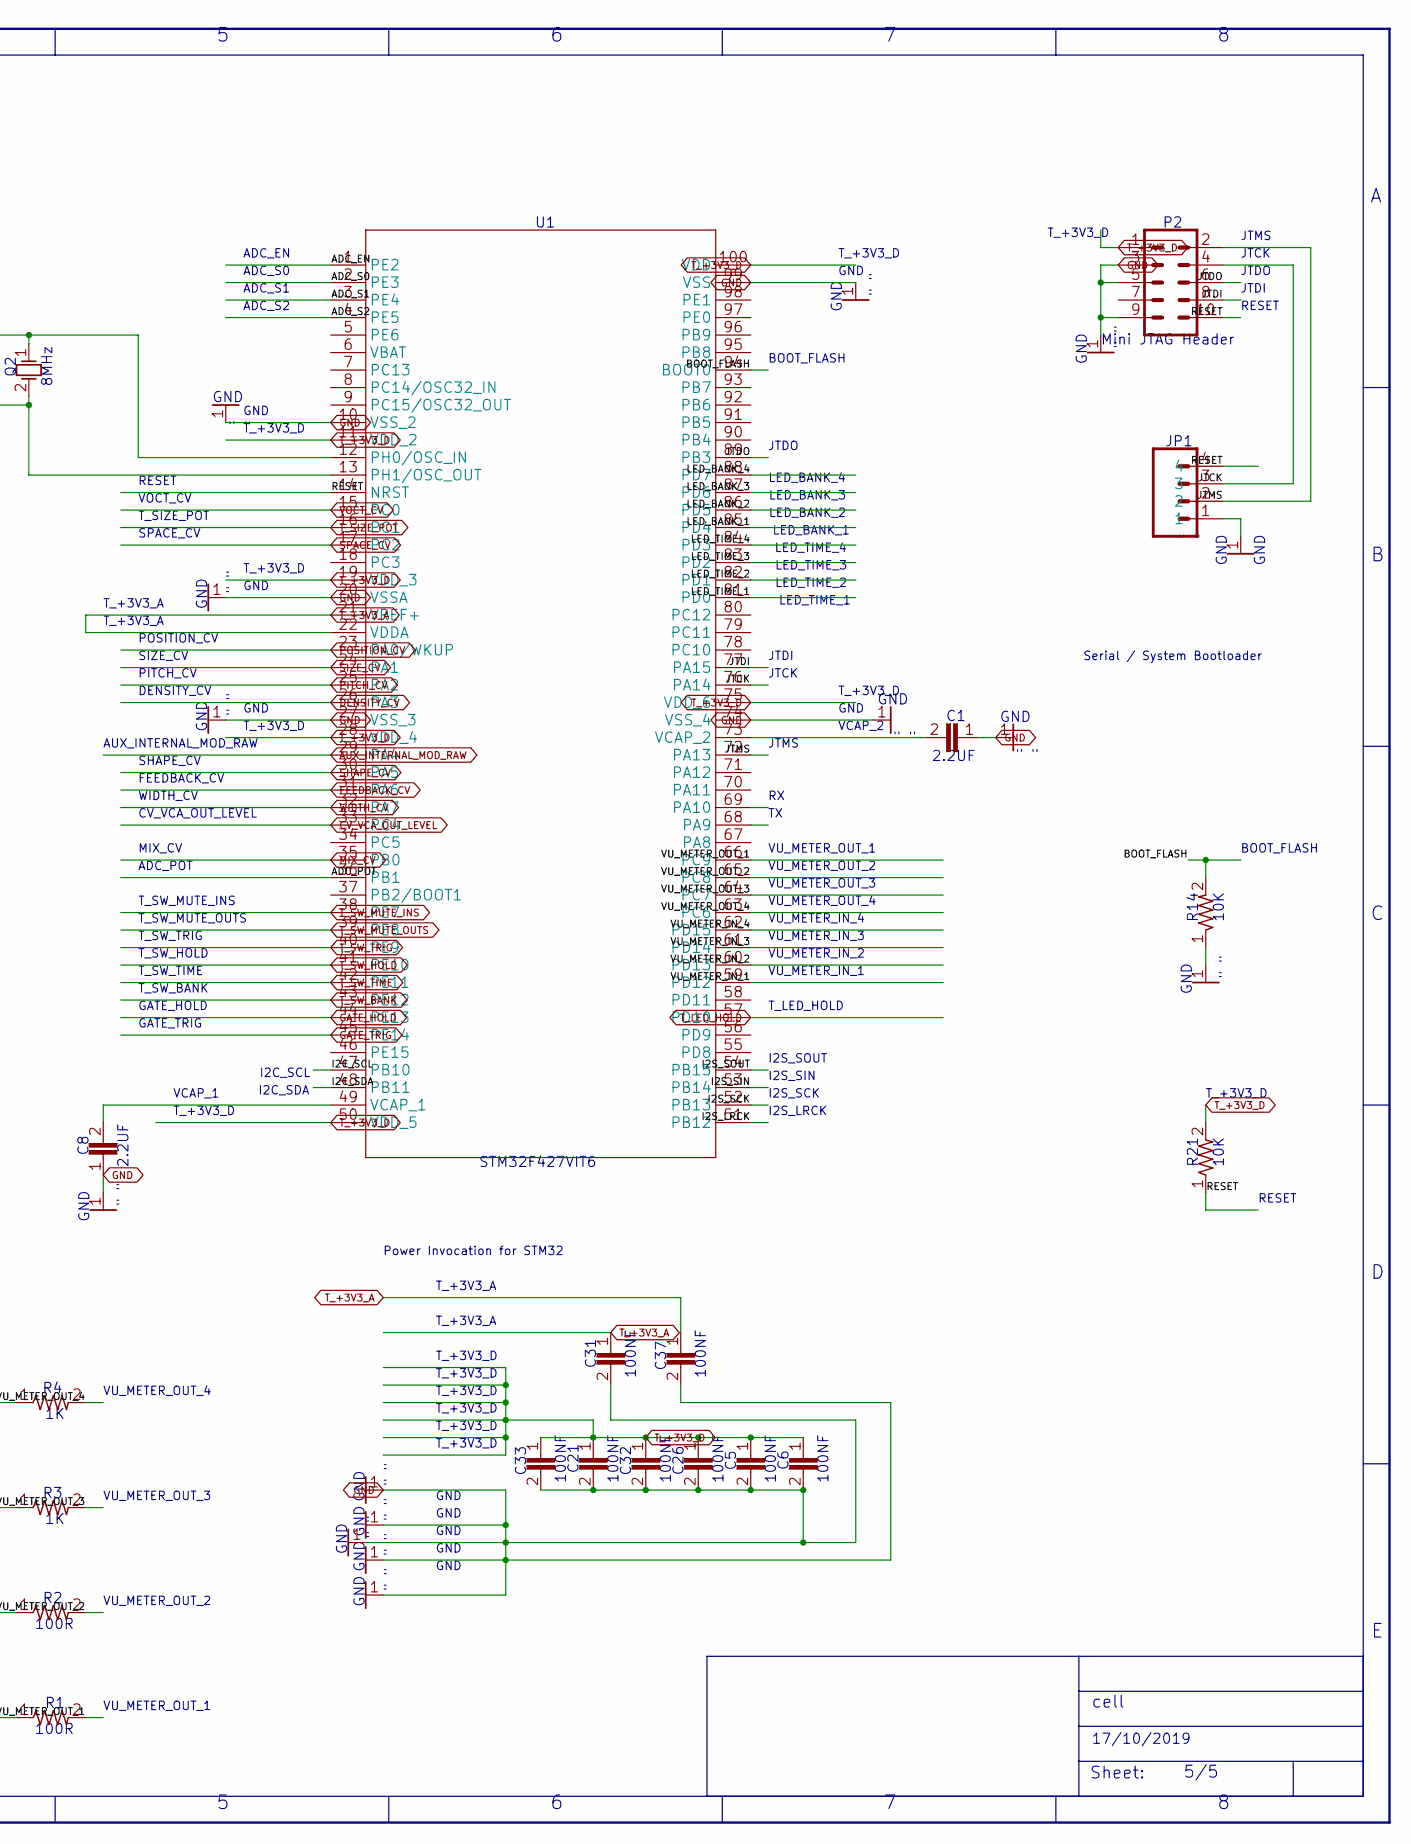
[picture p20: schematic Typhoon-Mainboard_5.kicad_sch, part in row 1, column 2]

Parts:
C1, C8: 2.2UF; CAP_0603
C2, C3: 18PF; CAP_0603
C5, C6, C7, C13, C21, C23, C26, C31, C32, C33, C37, C75: 100NF; CAP_0603
C17, C19, C29: 10UF; EC-4X7
C42, C43: 18p; CAP_0603
JP1: M04PTH; 1X04
P2: Mini JTAG Header; 2X5-1.27
Q1: 12.288MHz; TSC_7A_CRYSTAL
Q2: 8MHz; TSC_7A_CRYSTAL
R1, R2, R7, R8: 100R; RES_0603
R3, R4, R5, R6, R39, R42, R44, R46, R47, R48, R49, R50: 1K; RES_0603
R9, R11: 2K; RES_0603
R14, R21: 10K; RES_0603
U1: STM32F427VIT6; LQFP100-14X14MM
U2: WM8731; SSOP-28
U8: 4051; SO-16

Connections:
ADC_EN: U1.1 (PE2), U8.6 (INH)
ADC_POT: U1.36 (PB1), U8.3 (X)
ADC_S0: U1.2 (PE3), U8.11 (A)
ADC_S1: U1.3 (PE4), U8.10 (B)
ADC_S2: U1.4 (PE5), U8.9 (C)
AUX_INTERNAL_MOD_RAW: U1.29 (PA4); also elsewhere on the board
BOOT_FLASH: R14.2, U1.94 (BOOT0)
CV_VCA_OUT_LEVEL: U1.33 (PC4); also elsewhere on the board
DENSITY_CV: U1.26 (PA3); also elsewhere on the board
FEEDBACK_CV: U1.31 (PA6); also elsewhere on the board
GATE_HOLD: U1.44 (PE13); also elsewhere on the board
GATE_TRIG: U1.45 (PE14); also elsewhere on the board
I2C_SCL: R11.1, U1.47 (PB10), U2.24 (SCLK)
I2C_SDA: R9.1, U1.48 (PB11), U2.23 (SDIN)
I2S_LRCK: U1.51 (PB12), U2.5 (DACLRC), U2.7 (ADCLRC)
I2S_SCK: U1.52 (PB13), U2.3 (BCLK)
I2S_SIN: U1.53 (PB14), U2.6 (ADCDAT)
I2S_SOUT: U1.54 (PB15), U2.4 (DACDAT)
JTCK: JP1.3, P2.4, U1.76 (PA14)
JTDI: P2.8, U1.77 (PA15)
JTDO: P2.6, U1.89 (PB3)
JTMS: JP1.2, P2.2, U1.72 (PA13)
LED_BANK_1: R47.2, U1.85 (PD4)
LED_BANK_2: R48.2, U1.86 (PD5)
LED_BANK_3: R49.2, U1.87 (PD6)
LED_BANK_4: R50.2, U1.88 (PD7)
LED_TIME_1: R39.2, U1.81 (PD0)
LED_TIME_2: R42.2, U1.82 (PD1)
LED_TIME_3: R44.2, U1.83 (PD2)
LED_TIME_4: R46.2, U1.84 (PD3)
LIN: U2.20 (LLINEIN); also elsewhere on the board
LOUT: U2.12 (LOUT); also elsewhere on the board
MIX_CV: U1.35 (PB0); also elsewhere on the board
unnamed: C19.P$1 (POS), C23.1, U2.16 (VMID)
unnamed: C2.2, Q1.1 (OSC1), U2.26 (XTO)
unnamed: C3.2, Q1.2 (OSC2), U2.25 (XTI/MCLK)
unnamed: C42.2, Q2.1 (OSC1), U1.12 (PH0/OSC_IN)
Net_84: C43.2, Q2.2 (OSC2), U1.13 (PH1/OSC_OUT)
PITCH_CV: U1.25 (PA2); also elsewhere on the board
POSITION_CV: U1.23 (PA0/WKUP); also elsewhere on the board
RESET: JP1.4, P2.10, R21.1, U1.14 (NRST)
RIN: U2.19 (RLINEIN); also elsewhere on the board
ROUT: U2.13 (ROUT); also elsewhere on the board
SHAPE_CV: U1.30 (PA5); also elsewhere on the board
SIZE_CV: U1.24 (PA1); also elsewhere on the board
SPACE_CV: U1.17 (PC2); also elsewhere on the board
T_+3V3_A: C13.1, C17.P$1 (POS), C31.1, C37.1, C75.1, U1.21 (VREF+), U1.22 (VDDA), U2.8 (HPVDD), U2.14 (AVDD), U8.16 (VCC); also elsewhere on the board
T_DENSITY_POT: U8.4 (X7); also elsewhere on the board
T_FEEDBACK_POT: U8.14 (X1); also elsewhere on the board
T_LED_BANK_1: R47.1; also elsewhere on the board
T_LED_BANK_2: R48.1; also elsewhere on the board
T_LED_BANK_3: R49.1; also elsewhere on the board
T_LED_BANK_4: R50.1; also elsewhere on the board
T_LED_HOLD: U1.57 (PD10); also elsewhere on the board
T_LED_TIME_1: R39.1; also elsewhere on the board
T_LED_TIME_2: R42.1; also elsewhere on the board
T_LED_TIME_3: R44.1; also elsewhere on the board
T_LED_TIME_4: R46.1; also elsewhere on the board
T_MIX_POT: U8.12 (X3); also elsewhere on the board
T_PAN_POT: U8.13 (X0); also elsewhere on the board
T_PITCH_POT: U8.2 (X6); also elsewhere on the board
T_POSITION_POT: U8.1 (X4); also elsewhere on the board
T_SIZE_POT: U1.16 (PC1); also elsewhere on the board
T_SW_HOLD: U1.41 (PE10); also elsewhere on the board
T_SW_MUTE_OUTS: U1.39 (PE8); also elsewhere on the board
T_SW_TIME: U1.42 (PE11); also elsewhere on the board
T_SW_TRIG: U1.40 (PE9); also elsewhere on the board
T_TEXT_POT: U8.5 (X5); also elsewhere on the board
T_VERB_POT: U8.15 (X2); also elsewhere on the board
T_VU_METER_IN_1: R8.1; also elsewhere on the board
T_VU_METER_IN_2: R7.1; also elsewhere on the board
T_VU_METER_IN_3: R6.1; also elsewhere on the board
T_VU_METER_IN_4: R5.1; also elsewhere on the board
T_VU_METER_OUT_1: R1.1; also elsewhere on the board
T_VU_METER_OUT_2: R2.1; also elsewhere on the board
T_VU_METER_OUT_3: R3.1; also elsewhere on the board
T_VU_METER_OUT_4: R4.1; also elsewhere on the board
VCAP_1: C8.2, U1.49 (VCAP_1)
VCAP_2: C1.2, U1.73 (VCAP_2)
VOCT_CV: U1.15 (PC0); also elsewhere on the board
VU_METER_IN_1: R8.2, U1.59 (PD12)
VU_METER_IN_2: R7.2, U1.60 (PD13)
VU_METER_IN_3: R6.2, U1.61 (PD14)
VU_METER_IN_4: R5.2, U1.62 (PD15)
VU_METER_OUT_1: R1.2, U1.66 (PC9)
VU_METER_OUT_2: R2.2, U1.65 (PC8)
VU_METER_OUT_3: R3.2, U1.64 (PC7)
VU_METER_OUT_4: R4.2, U1.63 (PC6)
WIDTH_CV: U1.32 (PA7); also elsewhere on the board

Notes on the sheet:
C13
10K
JTDO
I2S_SOUT
GND
LED_TIME_1
R14
100NF
VU_METER_OUT_4
LED_BANK_2
JTMS
T_VU_METER_OUT_2
" "
T_+3V3_D
12.288MHz
18PF
WM8731
T_SW_TRIG
BOOT_FLASH
CV_VCA_OUT_LEVEL
100R
T_LED_TIME_2
T_+3V3_A
U8.A
ADC_S2
LED_BANK_4
LED_TIME_4
ROUT
JTCK
LED_TIME_2
LED_BANK_3
T_LED_TIME_1
C75
JTDI
T_SW_MUTE_INS
C42
VU_METER_OUT_2
I2S_LRCK
LED_BANK_1
I2C_SCL

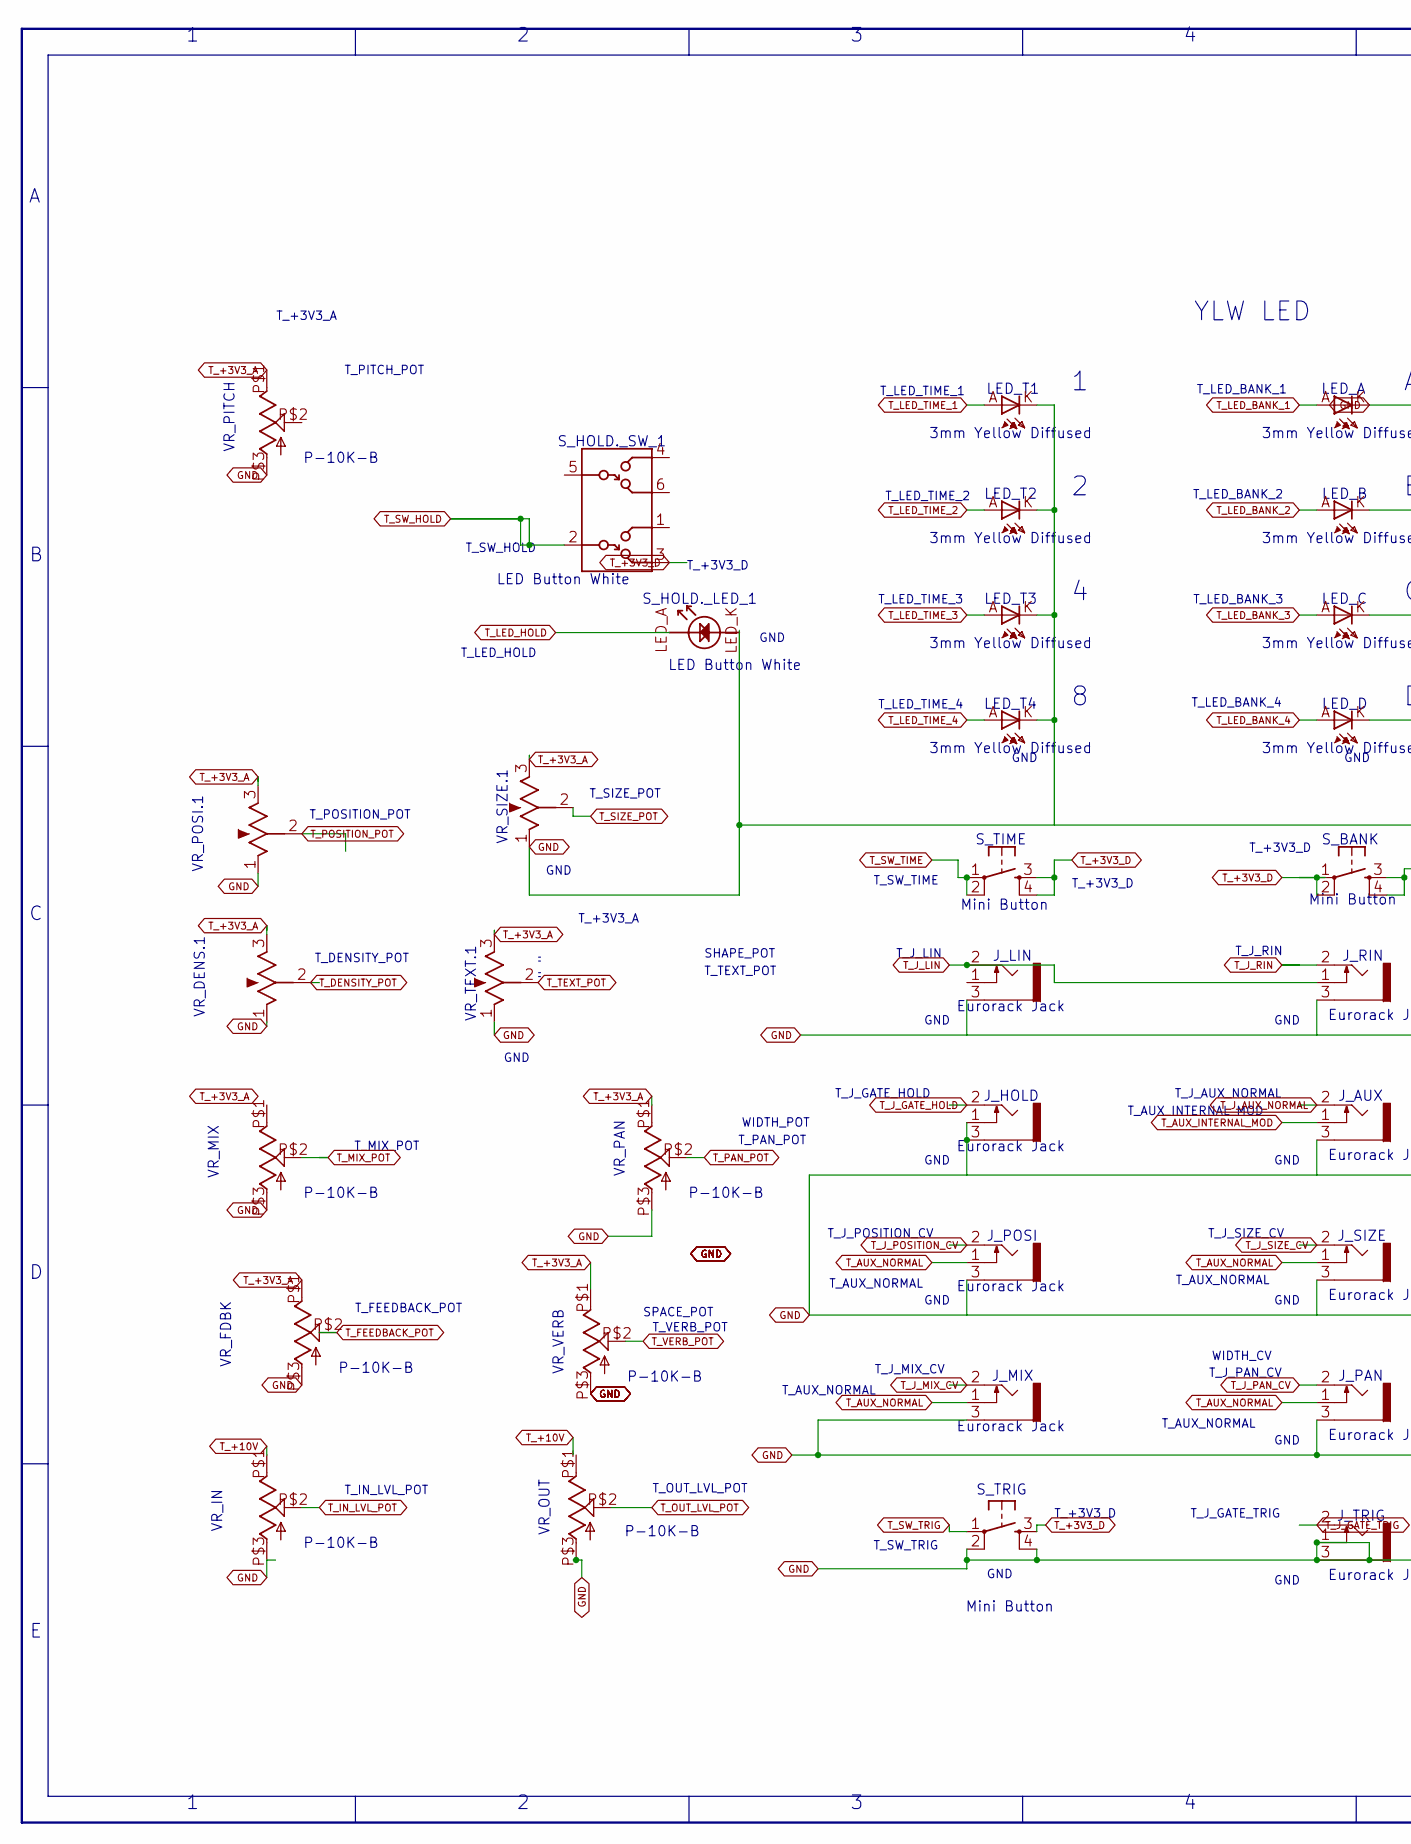
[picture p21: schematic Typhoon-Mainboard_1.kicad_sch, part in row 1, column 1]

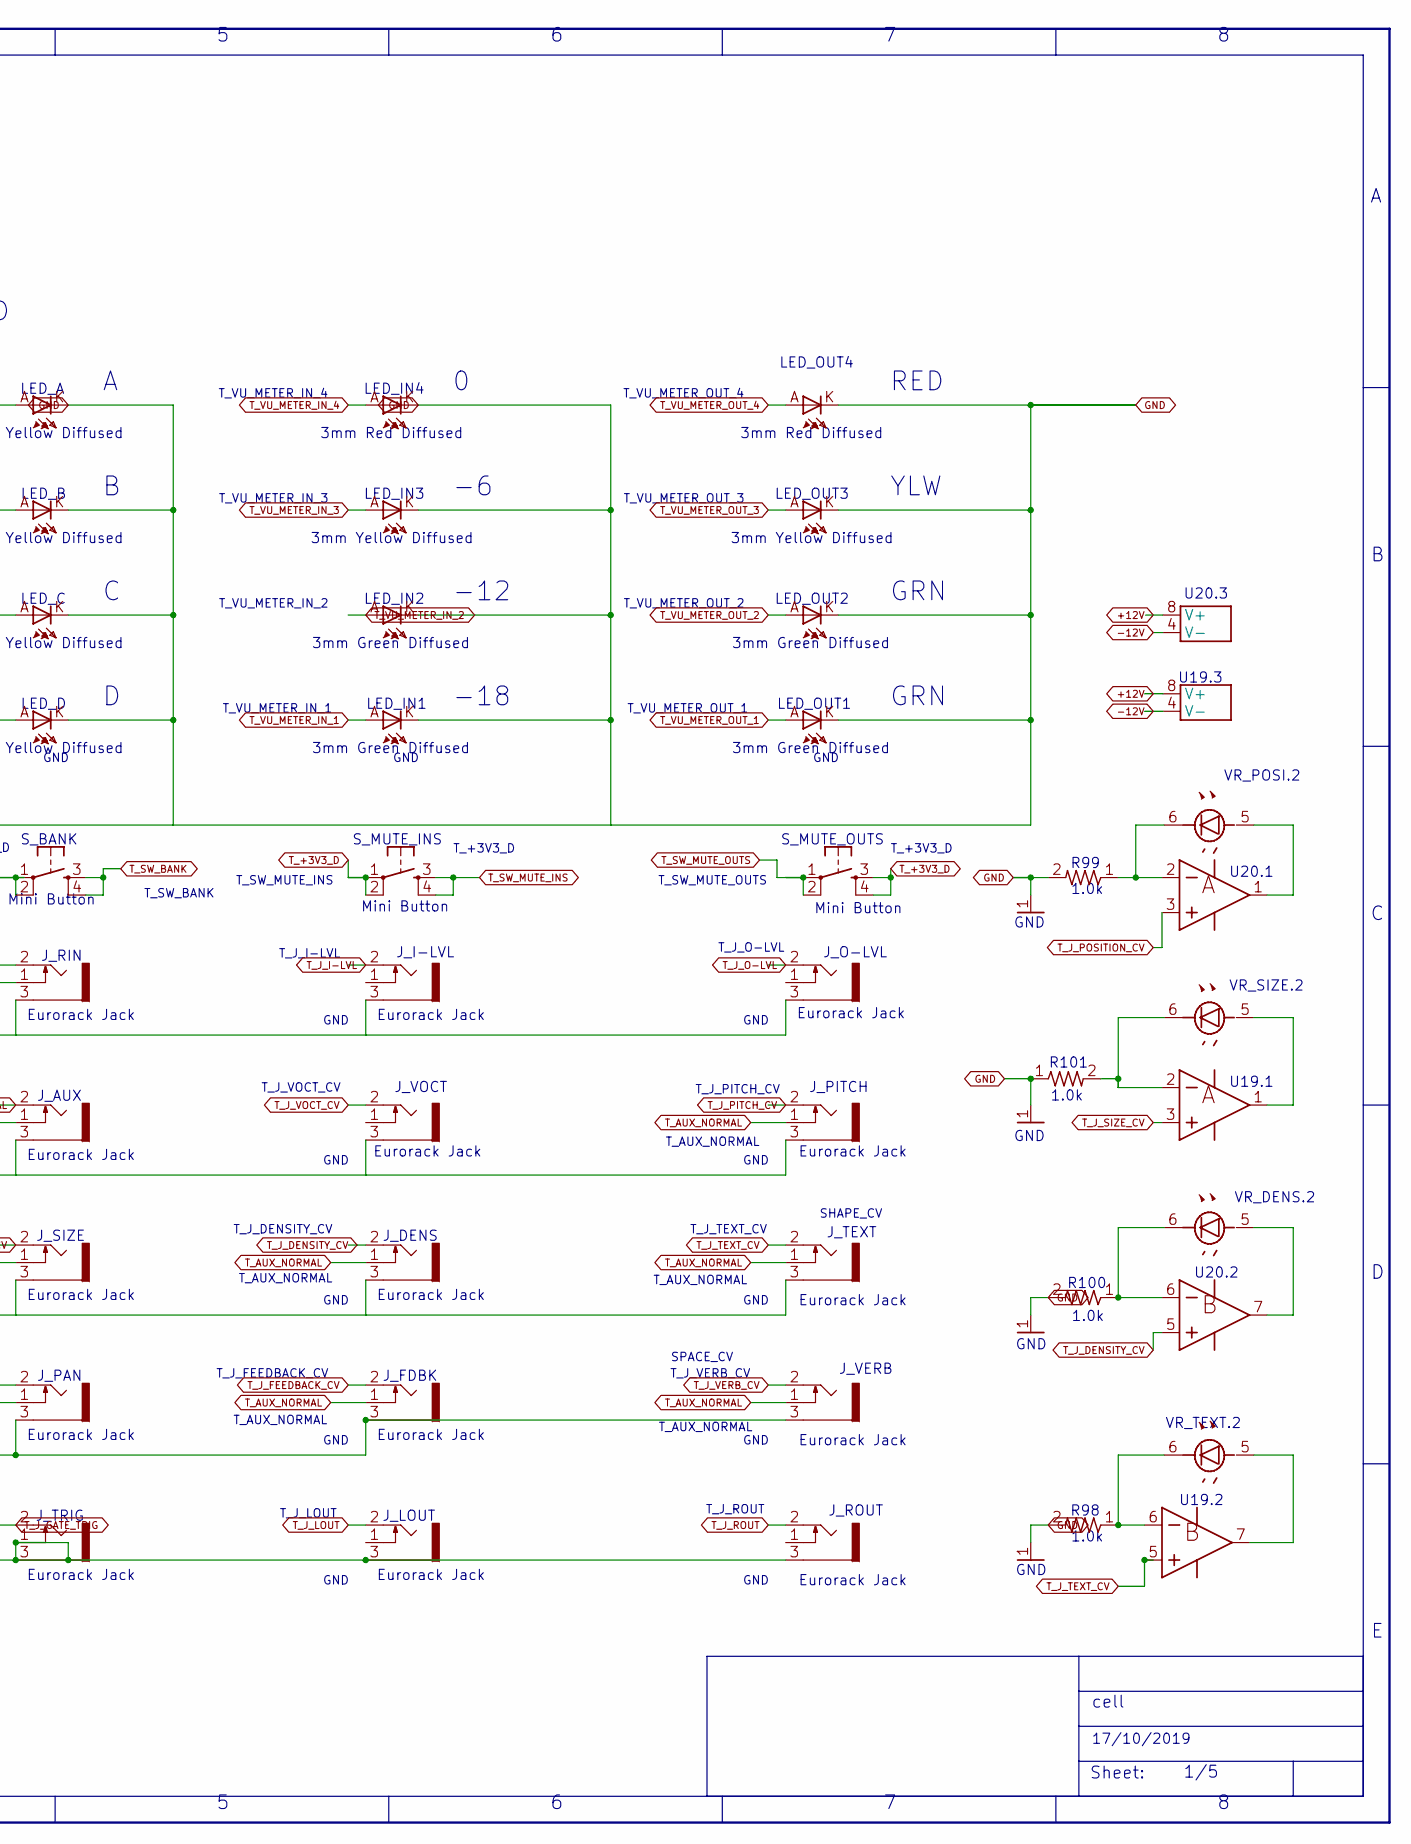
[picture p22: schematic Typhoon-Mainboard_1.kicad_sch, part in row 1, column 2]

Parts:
J_AUX0: Eurorack Jack; THONKICONN
J_DENS0: Eurorack Jack; THONKICONN
J_FDBK0: Eurorack Jack; THONKICONN
J_HOLD0: Eurorack Jack; THONKICONN
J_I-LVL0: Eurorack Jack; THONKICONN
J_LIN0: Eurorack Jack; THONKICONN
J_LOUT0: Eurorack Jack; THONKICONN
J_MIX0: Eurorack Jack; THONKICONN
J_O-LVL0: Eurorack Jack; THONKICONN
J_PAN0: Eurorack Jack; THONKICONN
J_PITCH0: Eurorack Jack; THONKICONN
J_POSI0: Eurorack Jack; THONKICONN
J_RIN0: Eurorack Jack; THONKICONN
J_ROUT0: Eurorack Jack; THONKICONN
J_SIZE0: Eurorack Jack; THONKICONN
J_TEXT0: Eurorack Jack; THONKICONN
J_TRIG0: Eurorack Jack; THONKICONN
J_VERB0: Eurorack Jack; THONKICONN
J_VOCT0: Eurorack Jack; THONKICONN
LED_A0: 3mm Yellow Diffused; LED_SILK
LED_B0: 3mm Yellow Diffused; LED_SILK
LED_C0: 3mm Yellow Diffused; LED_SILK
LED_D0: 3mm Yellow Diffused; LED_SILK
LED_IN1, LED_IN2: 3mm Green Diffused; LED_SILK
LED_IN3: 3mm Yellow Diffused; LED_SILK
LED_IN4: 3mm Red Diffused; LED_SILK
LED_OUT1, LED_OUT2: 3mm Green Diffused; LED_SILK
LED_OUT3: 3mm Yellow Diffused; LED_SILK
LED_OUT4: 3mm Red Diffused; LED_SILK
LED_T1, LED_T2, LED_T3, LED_T4: 3mm Yellow Diffused; LED_SILK
R98, R99, R100, R101: 1.0k; RES_0603
S_BANK0: Mini Button; TACTILE-PTH_SILK
S_HOLD0: LED Button White; LED_BUTTON_SILK
S_MUTE_INS0: Mini Button; TACTILE-PTH_SILK
S_MUTE_OUTS0: Mini Button; TACTILE-PTH_SILK
S_TIME0: Mini Button; TACTILE-PTH_SILK
S_TRIG0: Mini Button; TACTILE-PTH_SILK
U19, U20: TLV2172; TSSOP-8
VR_DENS0: BOURNS_PTL_LED_SLIDE_POT; BOURNS_PTL_30MM
VR_FDBK0: P-10K-B; ALPS_POT_VERTICAL_PS
VR_IN0: P-10K-B; ALPS_POT_VERTICAL_PS
VR_MIX0: P-10K-B; ALPS_POT_VERTICAL_PS
VR_OUT0: P-10K-B; ALPS_POT_VERTICAL_PS
VR_PAN0: P-10K-B; ALPS_POT_VERTICAL_PS
VR_PITCH0: P-10K-B; ALPS_POT_VERTICAL_PS
VR_POSI0: BOURNS_PTL_LED_SLIDE_POT; BOURNS_PTL_30MM
VR_SIZE0: BOURNS_PTL_LED_SLIDE_POT; BOURNS_PTL_30MM
VR_TEXT0: BOURNS_PTL_LED_SLIDE_POT; BOURNS_PTL_30MM
VR_VERB0: P-10K-B; ALPS_POT_VERTICAL_PS

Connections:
+12V: U19.8 (V+), U20.8 (V+); also elsewhere on the board
-12V: U19.4 (V-), U20.4 (V-); also elsewhere on the board
Net_1: R99.1, U20.2 (IN-), VR_POSI0.6 (gnd@2)
Net_110: R100.1, U20.6 (IN-), VR_DENS0.6 (gnd@2)
Net_116: R98.1, U19.6 (IN-), VR_TEXT0.6 (gnd@2)
Net_177: U20.1 (OUT), VR_POSI0.5 (gnd@1)
Net_178: U19.1 (OUT), VR_SIZE0.5 (gnd@1)
Net_182: U20.7 (OUT), VR_DENS0.5 (gnd@1)
Net_183: U19.7 (OUT), VR_TEXT0.5 (gnd@1)
T_+3V3_A: VR_DENS0.3 (CW), VR_FDBK0.P$1 (3), VR_MIX0.P$1 (3), VR_PAN0.P$1 (3), VR_PITCH0.P$1 (3), VR_POSI0.3 (CW), VR_SIZE0.3 (CW), VR_TEXT0.3 (CW), VR_VERB0.P$1 (3); also elsewhere on the board
T_+10V: VR_IN0.P$1 (3), VR_OUT0.P$1 (3); also elsewhere on the board
T_AUX_INTERNAL_MOD: J_AUX0.1 (NORM); also elsewhere on the board
T_AUX_NORMAL: J_DENS0.1 (NORM), J_FDBK0.1 (NORM), J_MIX0.1 (NORM), J_PAN0.1 (NORM), J_PITCH0.1 (NORM), J_POSI0.1 (NORM), J_SIZE0.1 (NORM), J_TEXT0.1 (NORM), J_VERB0.1 (NORM); also elsewhere on the board
T_DENSITY_POT: VR_DENS0.2 (W); also elsewhere on the board
T_FEEDBACK_POT: VR_FDBK0.P$2 (2); also elsewhere on the board
T_IN_LVL_POT: VR_IN0.P$2 (2); also elsewhere on the board
T_J_AUX_NORMAL: J_AUX0.2 (TIP); also elsewhere on the board
T_J_DENSITY_CV: J_DENS0.2 (TIP), U20.5 (IN+); also elsewhere on the board
T_J_FEEDBACK_CV: J_FDBK0.2 (TIP); also elsewhere on the board
T_J_GATE_HOLD: J_HOLD0.2 (TIP); also elsewhere on the board
T_J_GATE_TRIG: J_TRIG0.2 (TIP); also elsewhere on the board
T_J_I-LVL: J_I-LVL0.2 (TIP); also elsewhere on the board
T_J_LIN: J_LIN0.2 (TIP), J_RIN0.1 (NORM); also elsewhere on the board
T_J_LOUT: J_LOUT0.2 (TIP); also elsewhere on the board
T_J_MIX_CV: J_MIX0.2 (TIP); also elsewhere on the board
T_J_O-LVL: J_O-LVL0.2 (TIP); also elsewhere on the board
T_J_PAN_CV: J_PAN0.2 (TIP); also elsewhere on the board
T_J_PITCH_CV: J_PITCH0.2 (TIP); also elsewhere on the board
T_J_POSITION_CV: J_POSI0.2 (TIP), U20.3 (IN+); also elsewhere on the board
T_J_RIN: J_RIN0.2 (TIP); also elsewhere on the board
T_J_ROUT: J_ROUT0.2 (TIP); also elsewhere on the board
T_J_SIZE_CV: J_SIZE0.2 (TIP), U19.3 (IN+); also elsewhere on the board
T_J_TEXT_CV: J_TEXT0.2 (TIP), U19.5 (IN+); also elsewhere on the board
T_J_VERB_CV: J_VERB0.2 (TIP); also elsewhere on the board
T_J_VOCT_CV: J_VOCT0.2 (TIP); also elsewhere on the board
T_LED_BANK_1: LED_A0.A; also elsewhere on the board
T_LED_BANK_2: LED_B0.A; also elsewhere on the board
T_LED_BANK_3: LED_C0.A; also elsewhere on the board
T_LED_BANK_4: LED_D0.A; also elsewhere on the board
T_LED_HOLD: S_HOLD0.LED_A; also elsewhere on the board
T_LED_TIME_1: LED_T1.A; also elsewhere on the board
T_LED_TIME_2: LED_T2.A; also elsewhere on the board
T_LED_TIME_3: LED_T3.A; also elsewhere on the board
T_LED_TIME_4: LED_T4.A; also elsewhere on the board
T_MIX_POT: VR_MIX0.P$2 (2); also elsewhere on the board
T_OUT_LVL_POT: VR_OUT0.P$2 (2); also elsewhere on the board
T_PAN_POT: VR_PAN0.P$2 (2); also elsewhere on the board
T_PITCH_POT: VR_PITCH0.P$2 (2); also elsewhere on the board
T_POSITION_POT: VR_POSI0.2 (W); also elsewhere on the board
T_SIZE_POT: VR_SIZE0.2 (W); also elsewhere on the board
T_SW_HOLD: S_HOLD0.2; also elsewhere on the board
T_SW_MUTE_OUTS: S_MUTE_OUTS0.1, S_MUTE_OUTS0.2; also elsewhere on the board
T_SW_TIME: S_TIME0.1, S_TIME0.2; also elsewhere on the board
T_SW_TRIG: S_TRIG0.1; also elsewhere on the board
T_TEXT_POT: VR_TEXT0.2 (W); also elsewhere on the board
T_VERB_POT: VR_VERB0.P$2 (2); also elsewhere on the board
T_VU_METER_IN_1: LED_IN1.A; also elsewhere on the board
T_VU_METER_IN_2: LED_IN2.A; also elsewhere on the board
T_VU_METER_IN_3: LED_IN3.A; also elsewhere on the board
T_VU_METER_IN_4: LED_IN4.A; also elsewhere on the board
T_VU_METER_OUT_1: LED_OUT1.A; also elsewhere on the board
T_VU_METER_OUT_2: LED_OUT2.A; also elsewhere on the board
T_VU_METER_OUT_3: LED_OUT3.A; also elsewhere on the board
T_VU_METER_OUT_4: LED_OUT4.A; also elsewhere on the board

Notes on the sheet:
T_+3V3_A
GND
S_TIME
T_+3V3_D
Eurorack Jack
VR_TEXT.1
LED_OUT3
LED_IN3
T_J_GATE_TRIG
T_J_VERB_CV
T_VU_METER_IN_4
T_VU_METER_OUT_2
T_IN_LVL_POT
VR_PAN
WIDTH_POT
J_I-LVL
P-10K-B
1.0k
J_LIN
T_PITCH_POT
T_SW_HOLD
T_POSITION_POT
T_SW_TRIG
3mm Yellow Diffused
SHAPE_POT
T_LED_TIME_2
J_TRIG
J_AUX
3mm Red Diffused
S_MUTE_INS
T_SW_MUTE_OUTS
WIDTH_CV
T_J_POSITION_CV
T_AUX_NORMAL
VR_VERB
LED_IN1
Mini Button
LED_OUT2
VR_MIX
J_PITCH

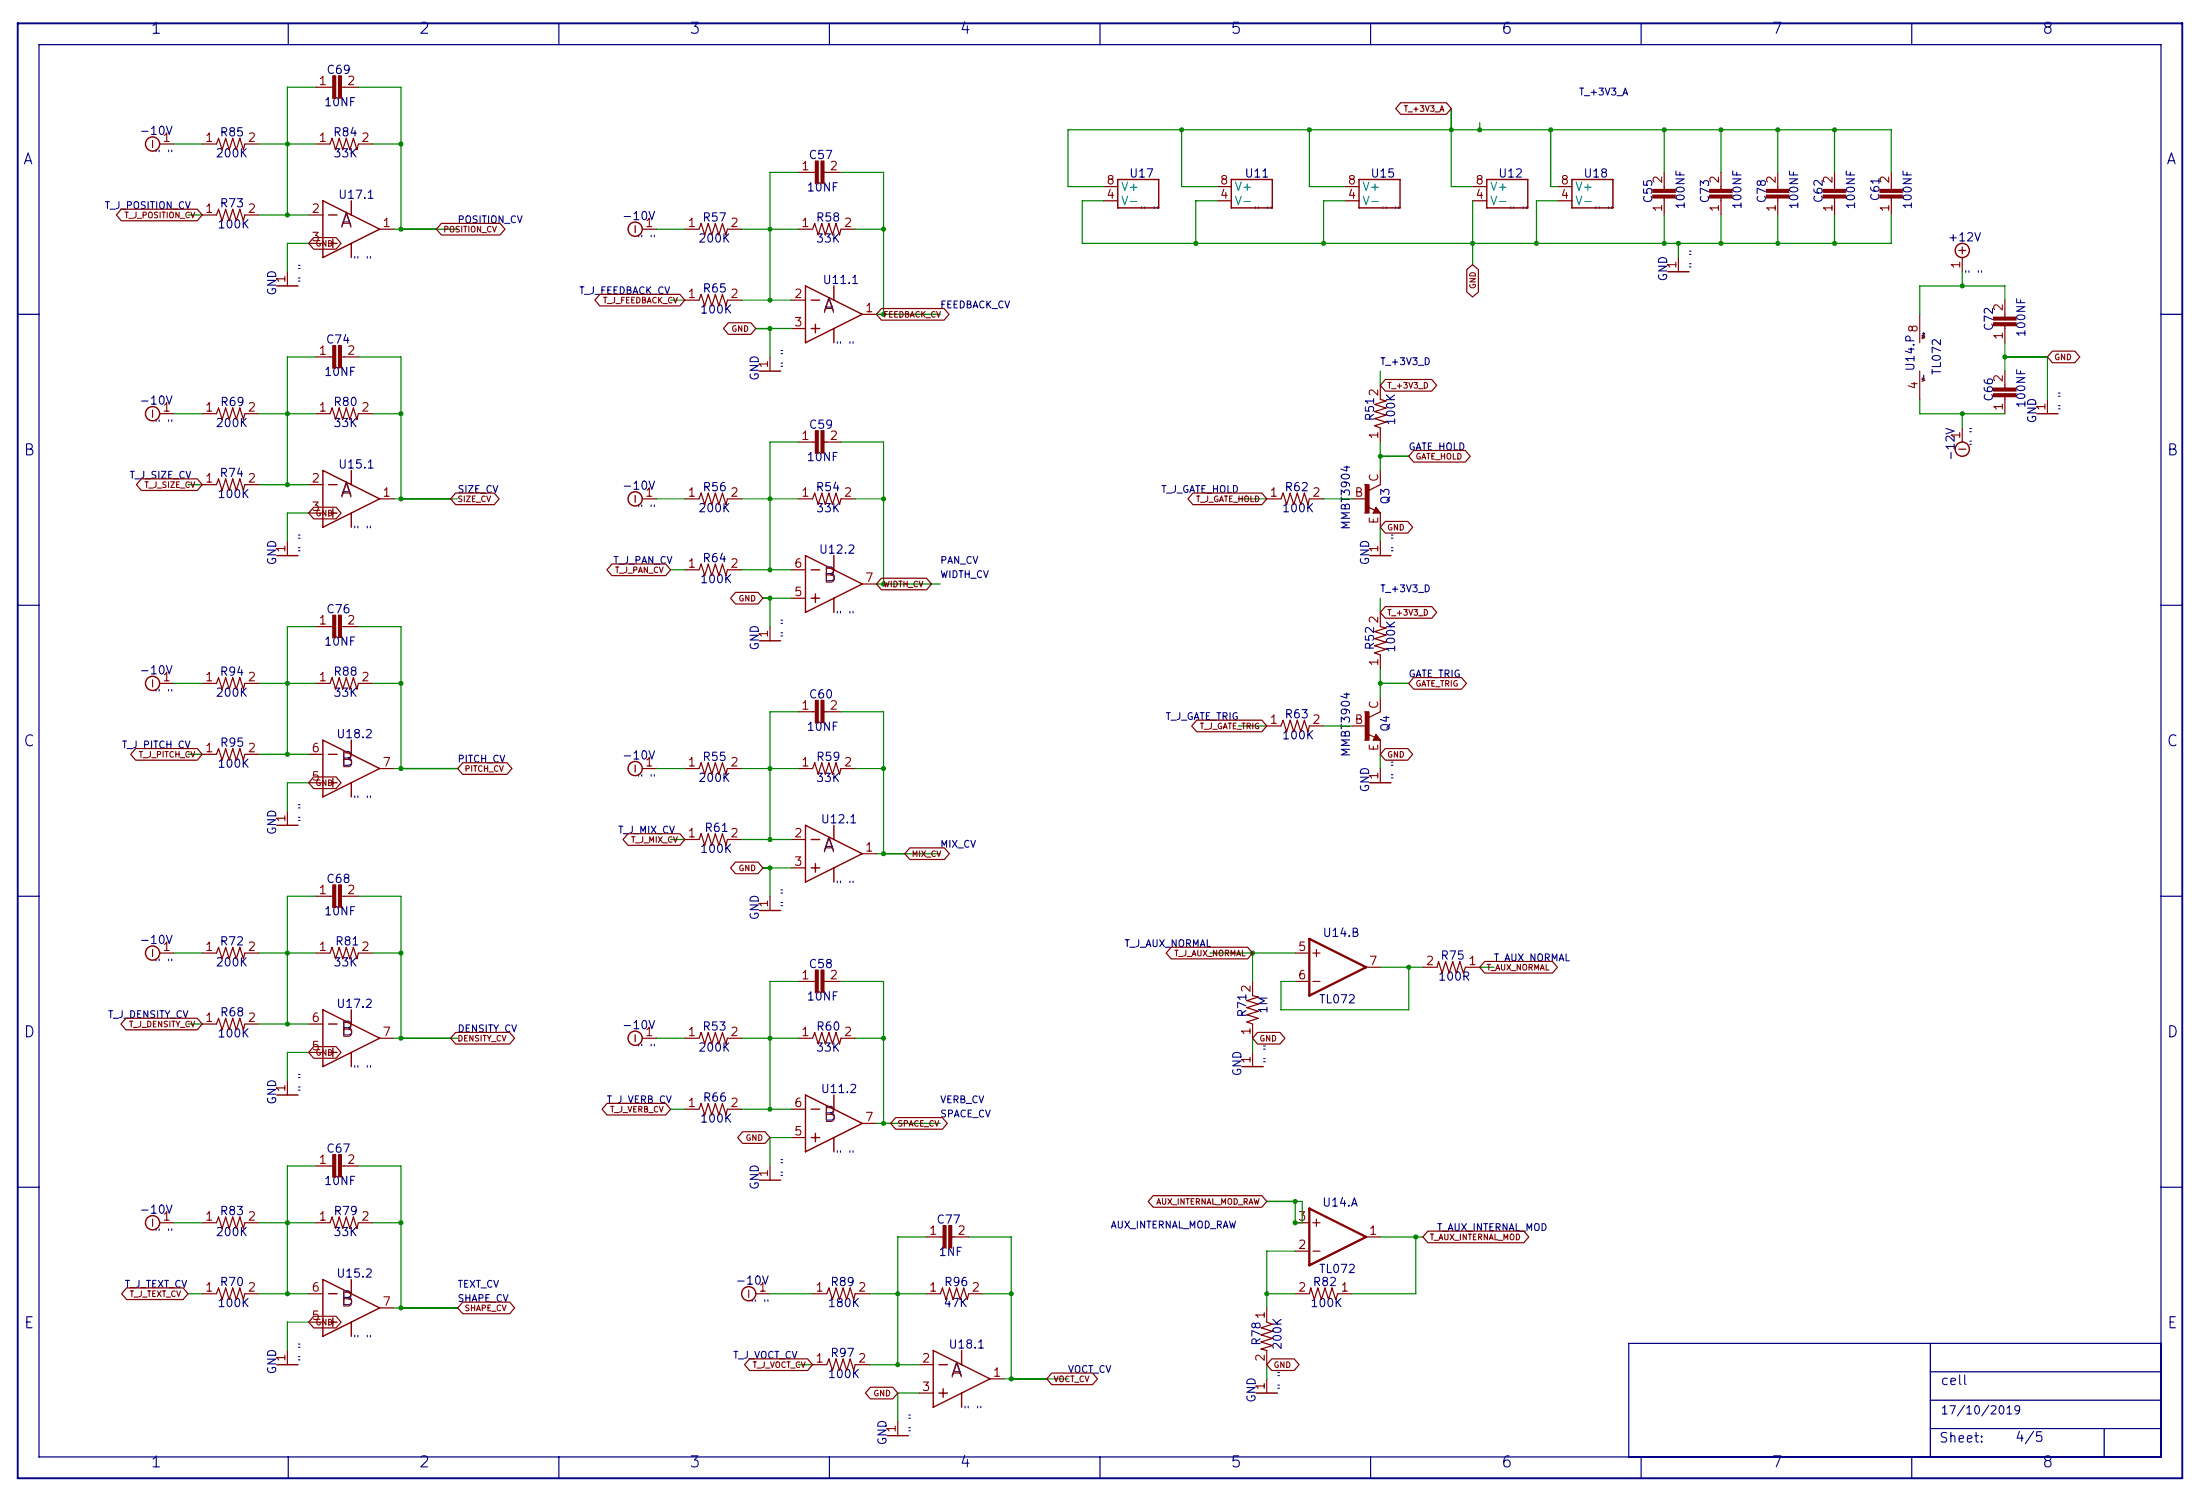
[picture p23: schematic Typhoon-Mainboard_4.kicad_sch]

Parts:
C55, C61, C62, C66, C72, C73, C78: 100NF; CAP_0603
C57, C58, C59, C60, C67, C68, C69, C74, C76: 10NF; CAP_0603
C77: 1NF; CAP_0603
Q3, Q4: MMBT3904; SOT23-BEC
R51, R52, R61, R62, R63, R64, R65, R66, R68, R70, R73, R74, R82, R95, R97: 100K; RES_0603
R53, R55, R56, R57, R69, R72, R78, R83, R85, R94: 200K; RES_0603
R54, R58, R59, R60, R79, R80, R81, R84, R88: 33K; RES_0603
R71: 1M; RES_0603
R75: 100R; RES_0603
R89: 180K; RES_0603
R96: 47K; RES_0603
U11, U12, U15, U17, U18: MCP6002; SOIC-8_150MIL
U14: TL072; SO-8

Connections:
+12V: C72.2, U14.8 (V+); also elsewhere on the board
-10V: R53.1, R55.1, R56.1, R57.1, R69.1, R72.1, R83.1, R85.1, R89.1, R94.1; also elsewhere on the board
-12V: C66.1, U14.4 (V-); also elsewhere on the board
AUX_INTERNAL_MOD_RAW: U14.3 (+IN); also elsewhere on the board
DENSITY_CV: C68.2, R81.2, U17.7 (OUT); also elsewhere on the board
FEEDBACK_CV: C57.2, R58.2, U11.1 (OUT); also elsewhere on the board
GATE_HOLD: Q3.C, R51.1; also elsewhere on the board
GATE_TRIG: Q4.C, R52.1; also elsewhere on the board
MIX_CV: C60.2, R59.2, U12.1 (OUT); also elsewhere on the board
unnamed: C74.1, R69.2, R74.2, R80.1, U15.2 (IN-)
unnamed: C76.1, R88.1, R94.2, R95.2, U18.6 (IN-)
unnamed: C68.1, R68.2, R72.2, R81.1, U17.6 (IN-)
unnamed: C57.1, R57.2, R58.1, R65.2, U11.2 (IN-)
unnamed: C59.1, R54.1, R56.2, R64.2, U12.6 (IN-)
unnamed: C60.1, R55.2, R59.1, R61.2, U12.2 (IN-)
unnamed: C58.1, R53.2, R60.1, R66.2, U11.6 (IN-)
unnamed: C67.1, R70.2, R79.1, R83.2, U15.6 (IN-)
unnamed: R75.2, U14.6 (-IN), U14.7 (OUT)
unnamed: Q3.B, R62.2
unnamed: C77.1, R89.2, R96.1, R97.2, U18.2 (IN-)
unnamed: Q4.B, R63.2
unnamed: C69.1, R73.2, R84.1, R85.2, U17.2 (IN-)
unnamed: R78.1, R82.2, U14.2 (-IN)
PITCH_CV: C76.2, R88.2, U18.7 (OUT); also elsewhere on the board
POSITION_CV: C69.2, R84.2, U17.1 (OUT); also elsewhere on the board
SHAPE_CV: C67.2, R79.2, U15.7 (OUT); also elsewhere on the board
SIZE_CV: C74.2, R80.2, U15.1 (OUT); also elsewhere on the board
SPACE_CV: C58.2, R60.2, U11.7 (OUT); also elsewhere on the board
T_+3V3_A: C55.2, C61.2, C62.2, C73.2, C78.2, U11.8 (V+), U12.8 (V+), U15.8 (V+), U17.8 (V+), U18.8 (V+); also elsewhere on the board
T_AUX_INTERNAL_MOD: R82.1, U14.1 (OUT); also elsewhere on the board
T_AUX_NORMAL: R75.1; also elsewhere on the board
T_J_AUX_NORMAL: R71.2, U14.5 (+IN); also elsewhere on the board
T_J_DENSITY_CV: R68.1; also elsewhere on the board
T_J_FEEDBACK_CV: R65.1; also elsewhere on the board
T_J_GATE_HOLD: R62.1; also elsewhere on the board
T_J_GATE_TRIG: R63.1; also elsewhere on the board
T_J_MIX_CV: R61.1; also elsewhere on the board
T_J_PAN_CV: R64.1; also elsewhere on the board
T_J_PITCH_CV: R95.1; also elsewhere on the board
T_J_POSITION_CV: R73.1; also elsewhere on the board
T_J_SIZE_CV: R74.1; also elsewhere on the board
T_J_TEXT_CV: R70.1; also elsewhere on the board
T_J_VERB_CV: R66.1; also elsewhere on the board
T_J_VOCT_CV: R97.1; also elsewhere on the board
VOCT_CV: C77.2, R96.2, U18.1 (OUT); also elsewhere on the board
WIDTH_CV: C59.2, R54.2, U12.7 (OUT); also elsewhere on the board

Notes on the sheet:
R59
100K
GND
" "
C60
T_AUX_NORMAL
U14.A
R65
+12V
GATE_TRIG
-10V
T_J_FEEDBACK_CV
C55
C72
10NF
TEXT_CV
T_AUX_INTERNAL_MOD
VERB_CV
C78
33K
PAN_CV
T_J_PITCH_CV
T_J_PAN_CV
U14.P
R66
100NF
C57
R80
U17.2
C76
R88
MMBT3904
U18
200K
R83
FEEDBACK_CV
R55
R85
R73
1NF

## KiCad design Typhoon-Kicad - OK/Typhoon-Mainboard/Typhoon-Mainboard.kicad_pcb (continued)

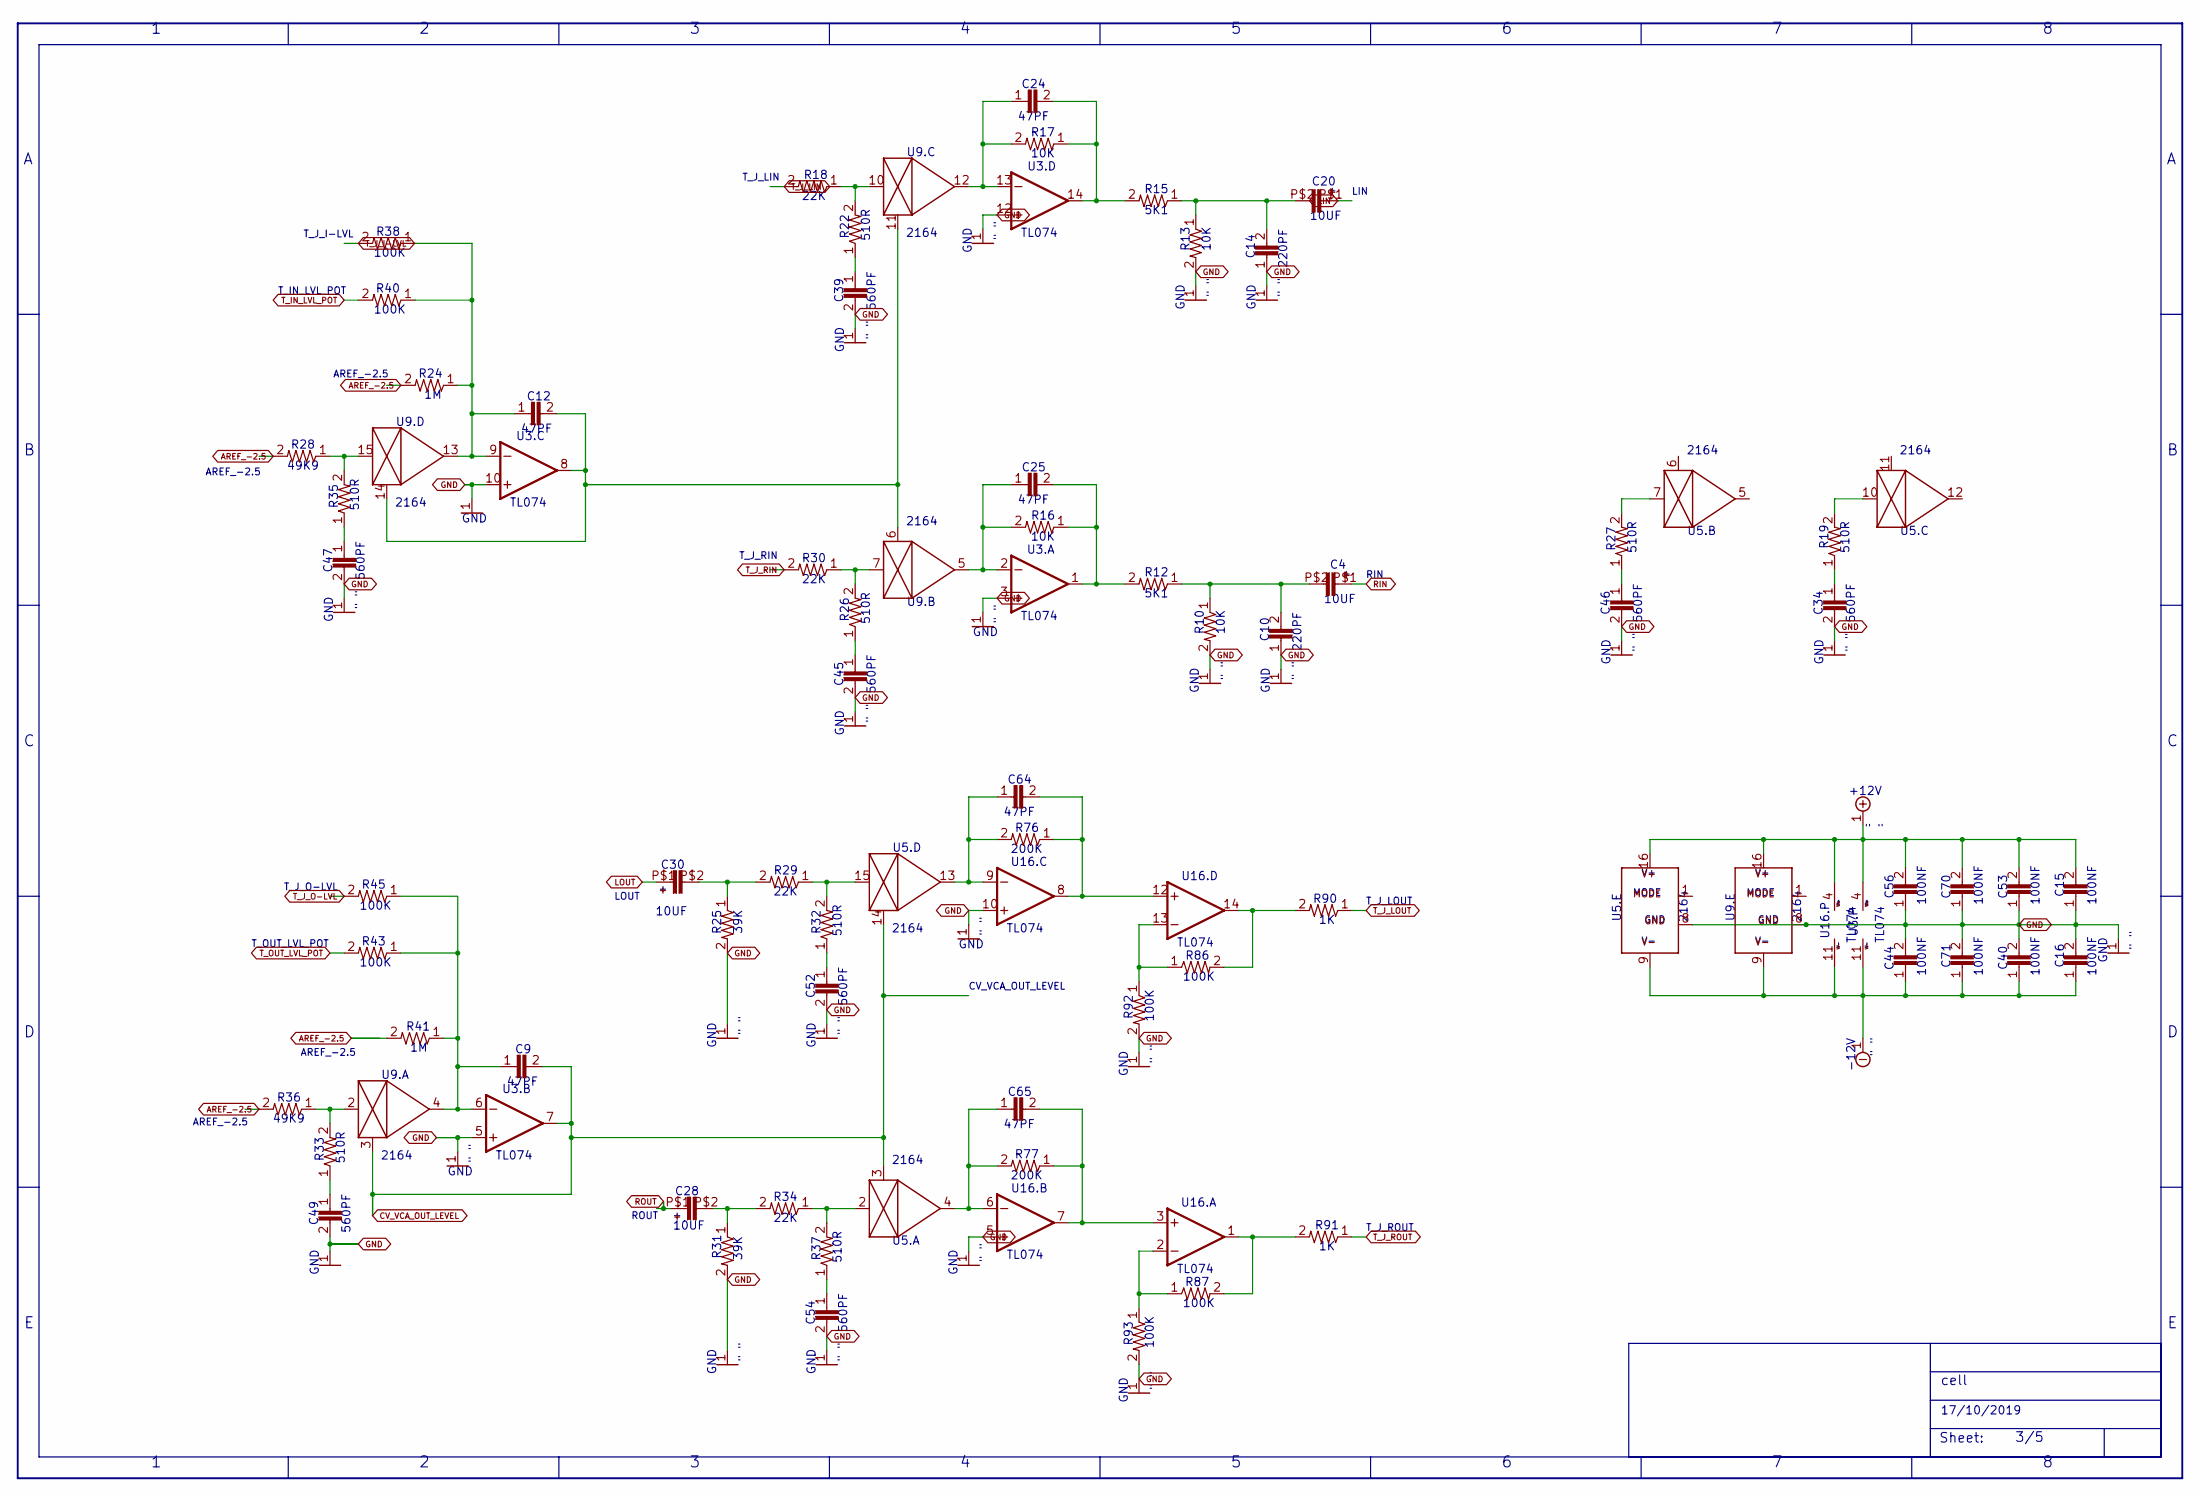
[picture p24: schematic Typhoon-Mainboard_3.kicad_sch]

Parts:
C4, C20, C28, C30: 10UF; EC-4X7
C9, C12, C24, C25, C64, C65: 47PF; CAP_0603
C10, C14: 220PF; CAP_0603
C15, C16, C40, C44, C53, C56, C70, C71: 100NF; CAP_0603
C34, C39, C45, C46, C47, C49, C52, C54: 560PF; CAP_0603
R10, R13, R16, R17: 10K; RES_0603
R12, R15: 5K1; RES_0603
R18, R29, R30, R34: 22K; RES_0603
R19, R22, R26, R27, R32, R33, R35, R37: 510R; RES_0603
R24, R41: 1M; RES_0603
R25, R31: 39K; RES_0603
R28, R36: 49K9; RES_0603
R38, R40, R43, R45, R86, R87, R92, R93: 100K; RES_0603
R76, R77: 200K; RES_0603
R90, R91: 1K; RES_0603
U3, U16: TL074; SO-14
U5, U9: 2164; SO-16

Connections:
+12V: C15.2, C53.2, C56.2, C70.2, U3.4 (V+), U5.16 (V+), U9.16 (V+), U16.4 (V+); also elsewhere on the board
-12V: C16.1, C40.1, C44.1, C71.1, U3.11 (V-), U5.9 (V-), U9.9 (V-), U16.11 (V-); also elsewhere on the board
AREF_-2.5: R24.2, R28.2, R36.2, R41.2; also elsewhere on the board
CV_VCA_OUT_LEVEL: C9.2, U3.7 (OUT), U5.3 (CTRL), U5.14 (CTRL), U9.3 (CTRL); also elsewhere on the board
LIN: C20.P$1 (POS); also elsewhere on the board
LOUT: C30.P$1 (POS); also elsewhere on the board
unnamed: C39.1, R22.1
unnamed: C45.1, R26.1
unnamed: C47.1, R35.1
unnamed: C12.2, U3.8 (OUT), U9.6 (CTRL), U9.11 (CTRL), U9.14 (CTRL)
unnamed: R26.2, R30.1, U9.7 (IN)
unnamed: R28.1, R35.2, U9.15 (IN)
unnamed: C25.1, R16.2, U3.2 (-IN), U9.5 (OUT)
unnamed: C25.2, R12.2, R16.1, U3.1 (OUT)
unnamed: C49.1, R33.1
unnamed: R33.2, R36.1, U9.2 (IN)
unnamed: C64.1, R76.2, U5.13 (OUT), U16.9 (-IN)
unnamed: C64.2, R76.1, U16.8 (OUT), U16.12 (+IN)
unnamed: R18.1, R22.2, U9.10 (IN)
unnamed: R27.2, U5.7 (IN)
unnamed: R29.1, R32.2, U5.15 (IN)
unnamed: C52.1, R32.1
unnamed: C30.P$2 (NEG), R25.1, R29.2
unnamed: C4.P$2 (NEG), C10.2, R10.1, R12.1
unnamed: C65.1, R77.2, U5.4 (OUT), U16.6 (-IN)
unnamed: C65.2, R77.1, U16.3 (+IN), U16.7 (OUT)
unnamed: R34.1, R37.2, U5.2 (IN)
unnamed: C54.1, R37.1
unnamed: C28.P$2 (NEG), R31.1, R34.2
unnamed: R19.2, U5.10 (IN)
unnamed: C24.1, R17.2, U3.13 (-IN), U9.12 (OUT)
unnamed: C24.2, R15.2, R17.1, U3.14 (OUT)
unnamed: R86.1, R92.1, U16.13 (-IN)
unnamed: C46.1, R27.1
unnamed: C34.1, R19.1
unnamed: R86.2, R90.2, U16.14 (OUT)
unnamed: R87.1, R93.1, U16.2 (-IN)
unnamed: R87.2, R91.2, U16.1 (OUT)
unnamed: C14.2, C20.P$2 (NEG), R13.1, R15.1
RIN: C4.P$1 (POS); also elsewhere on the board
ROUT: C28.P$1 (POS); also elsewhere on the board
T_IN_LVL_POT: R40.2; also elsewhere on the board
T_J_I-LVL: R38.2; also elsewhere on the board
T_J_LIN: R18.2; also elsewhere on the board
T_J_LOUT: R90.1; also elsewhere on the board
T_J_O-LVL: R45.2; also elsewhere on the board
T_J_RIN: R30.2; also elsewhere on the board
T_J_ROUT: R91.1; also elsewhere on the board
T_OUT_LVL_POT: R43.2; also elsewhere on the board
VCA_CTRL_INPUTS: C12.1, R24.1, R38.1, R40.1, U3.9 (-IN), U9.13 (OUT)
VCA_CTRL_INPUTS1: C9.1, R41.1, R43.1, R45.1, U3.6 (-IN), U9.4 (OUT)

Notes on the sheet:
TL074
C10
220PF
C64
R30
" "
R26
47PF
100NF
510R
C34
T_J_O-LVL
GND
22K
U9.D
560PF
C44
2164
R93
100K
T_J_ROUT
R24
10K
10UF
C70
U3.D
17/10/2019
R32
R91
C45
5K1
R90
RIN
MODE
R17
C53
U9.A
49K9
200K
C65

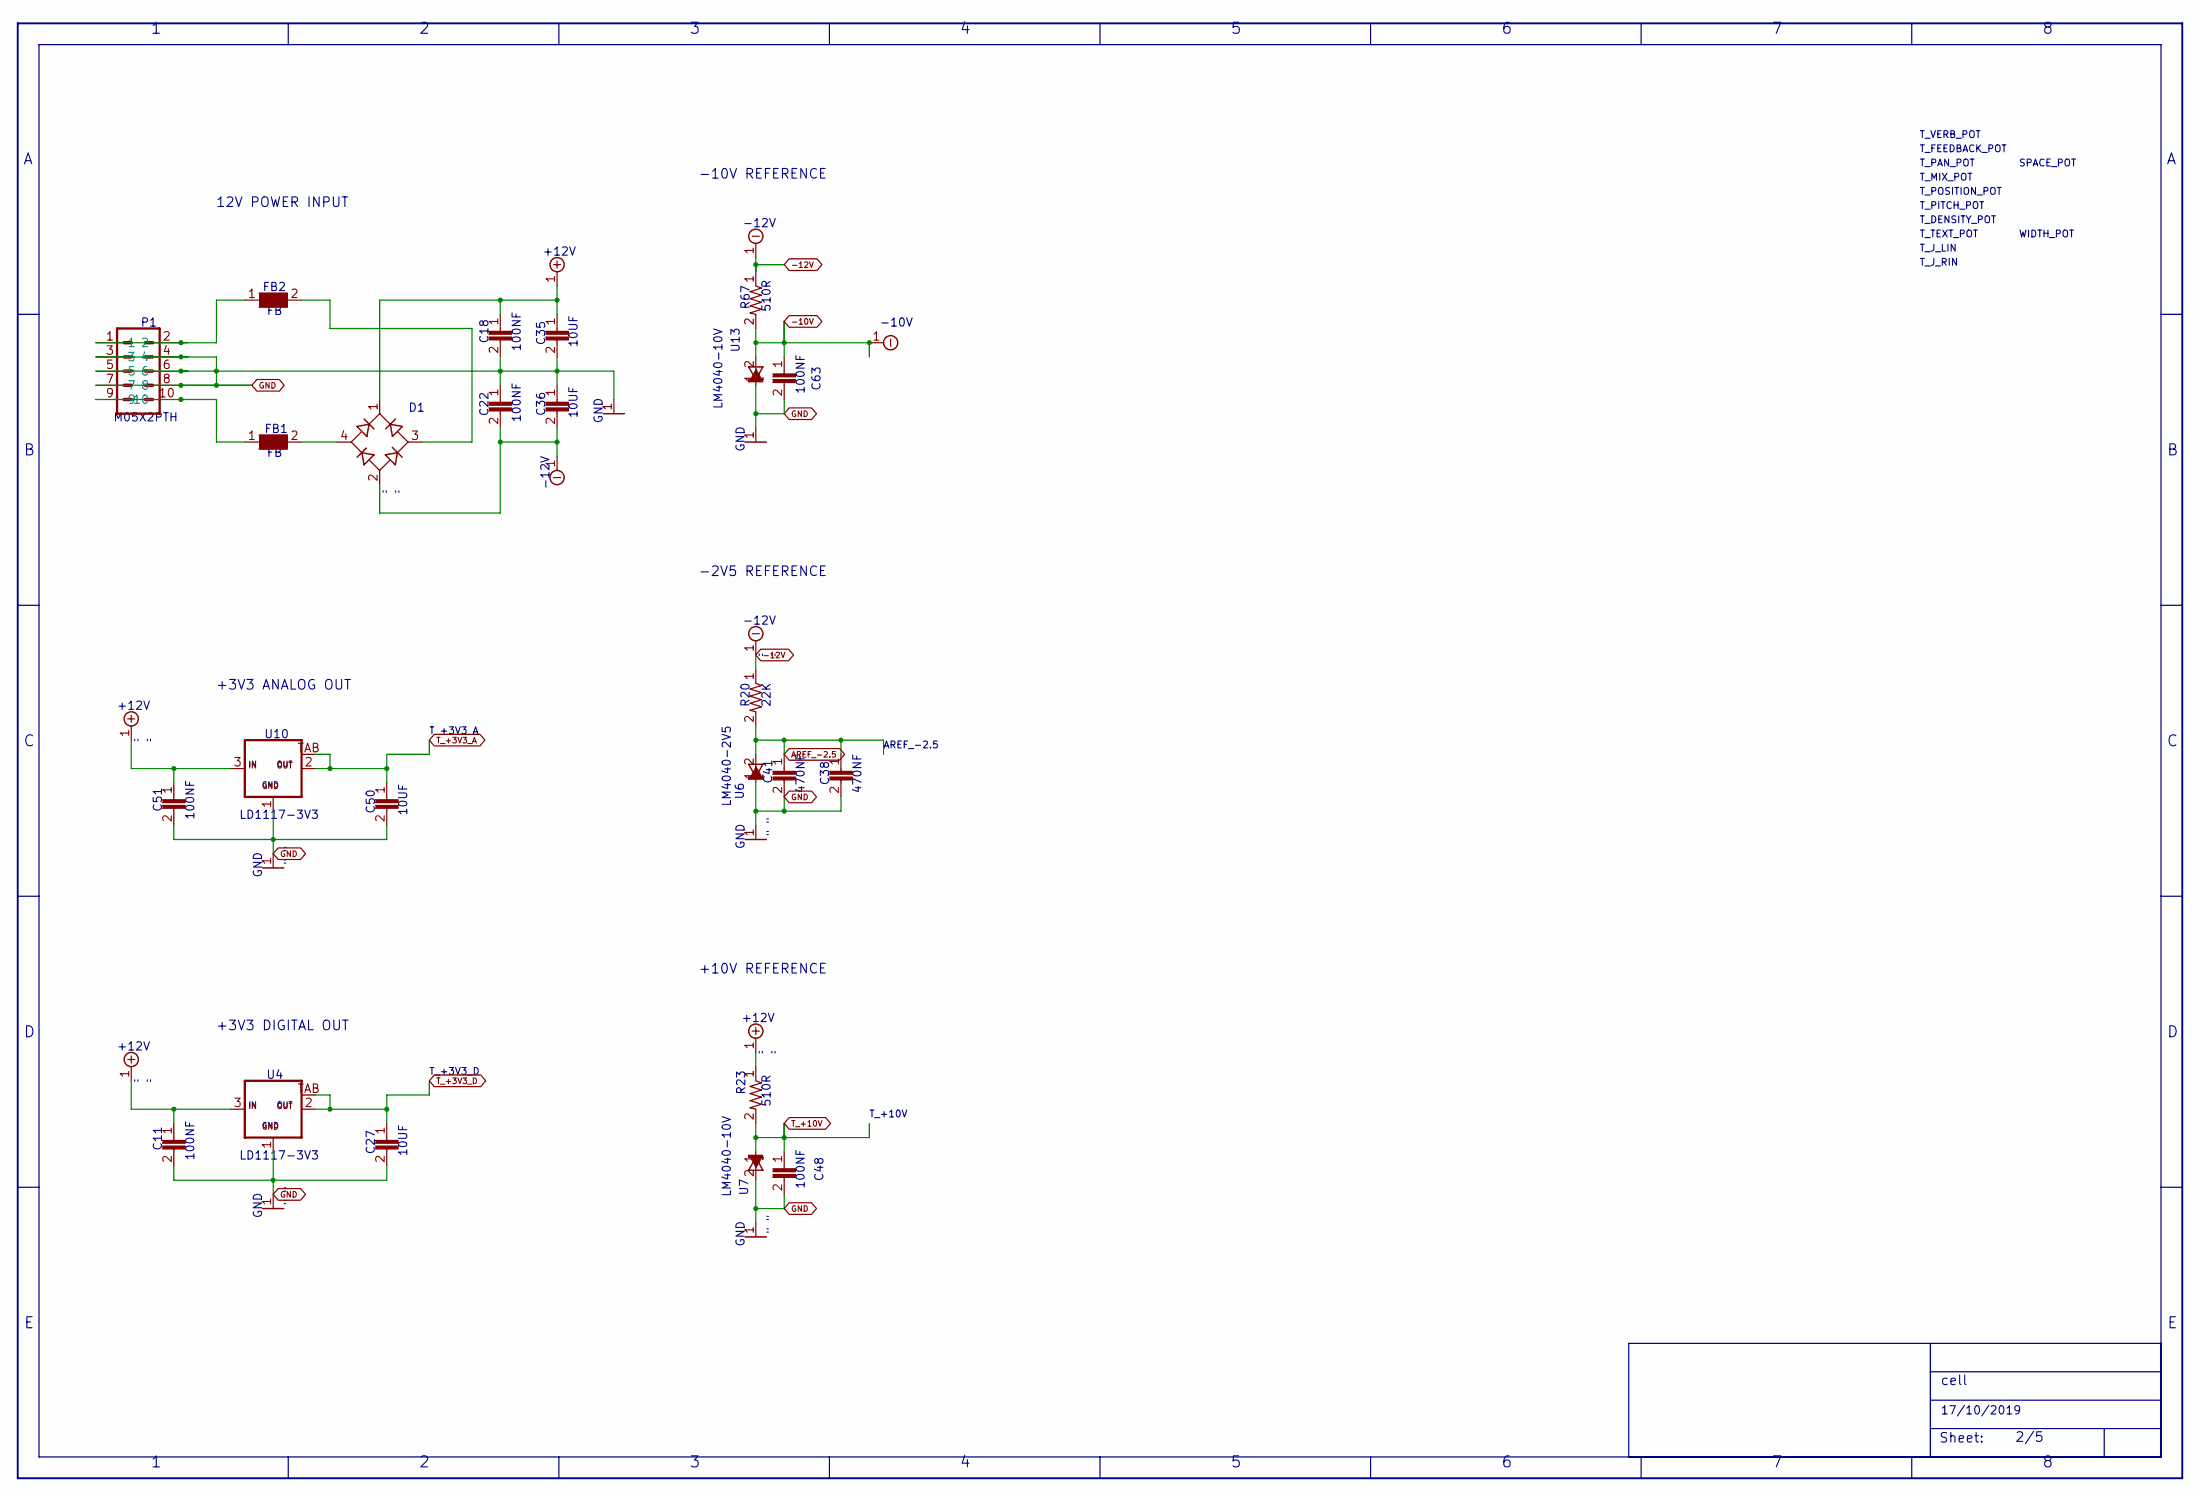
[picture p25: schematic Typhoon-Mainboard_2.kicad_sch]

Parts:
C11, C18, C22, C48, C51, C63: 100NF; CAP_0603
C27, C35, C36, C50: 10UF; C0805
C38, C41: 470NF; CAP_0603
D1: MB1S; SOP-4_6.5X2.54
FB1, FB2: FB; WUERTH-ELEKTRONIK_0603
P1: M05X2PTH; AVR_ICSP
R20: 22K; RES_0603
R23, R67: 510R; RES_0603
U4, U10: LD1117-3V3; SOT223
U6: LM4040-2V5; DBZ_R-PDSO-G3
U7, U13: LM4040-10V; DBZ_R-PDSO-G3

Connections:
+12V: C11.1, C18.1, C35.1, C51.1, D1.1 (+), R23.1, U4.3 (IN), U10.3 (IN); also elsewhere on the board
-10V: C63.1, R67.2, U13.2 (A); also elsewhere on the board
-12V: C22.2, C36.2, D1.2 (-), R20.1, R67.1; also elsewhere on the board
AREF_-2.5: C38.1, C41.1, R20.2, U6.2 (A); also elsewhere on the board
unnamed: FB2.1, P1.1, P1.2
unnamed: FB1.1, P1.9, P1.10
Net_38: D1.4 (AC1), FB1.2
Net_40: D1.3 (AC2), FB2.2
T_+3V3_A: C50.1, U10.2 (OUT), U10.TAB (OUT1); also elsewhere on the board
T_+10V: C48.1, R23.2, U7.1 (C); also elsewhere on the board

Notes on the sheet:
10UF
WIDTH_POT
T_J_RIN
SPACE_POT
-12V
C35
U13
+12V
C50
T_DENSITY_POT
+3V3 DIGITAL OUT
+10V REFERENCE
GND
T_+10V
cell
" "
M05X2PTH
100NF
LD1117-3V3
17/10/2019
12V POWER INPUT
C27
U10
R20
-10V REFERENCE
510R
T_J_LIN
C48
-10V
C22
T_PAN_POT
T_+3V3_D
FB1
C63
T_TEXT_POT
T_MIX_POT
Sheet:
LM4040-10V
C18
470NF

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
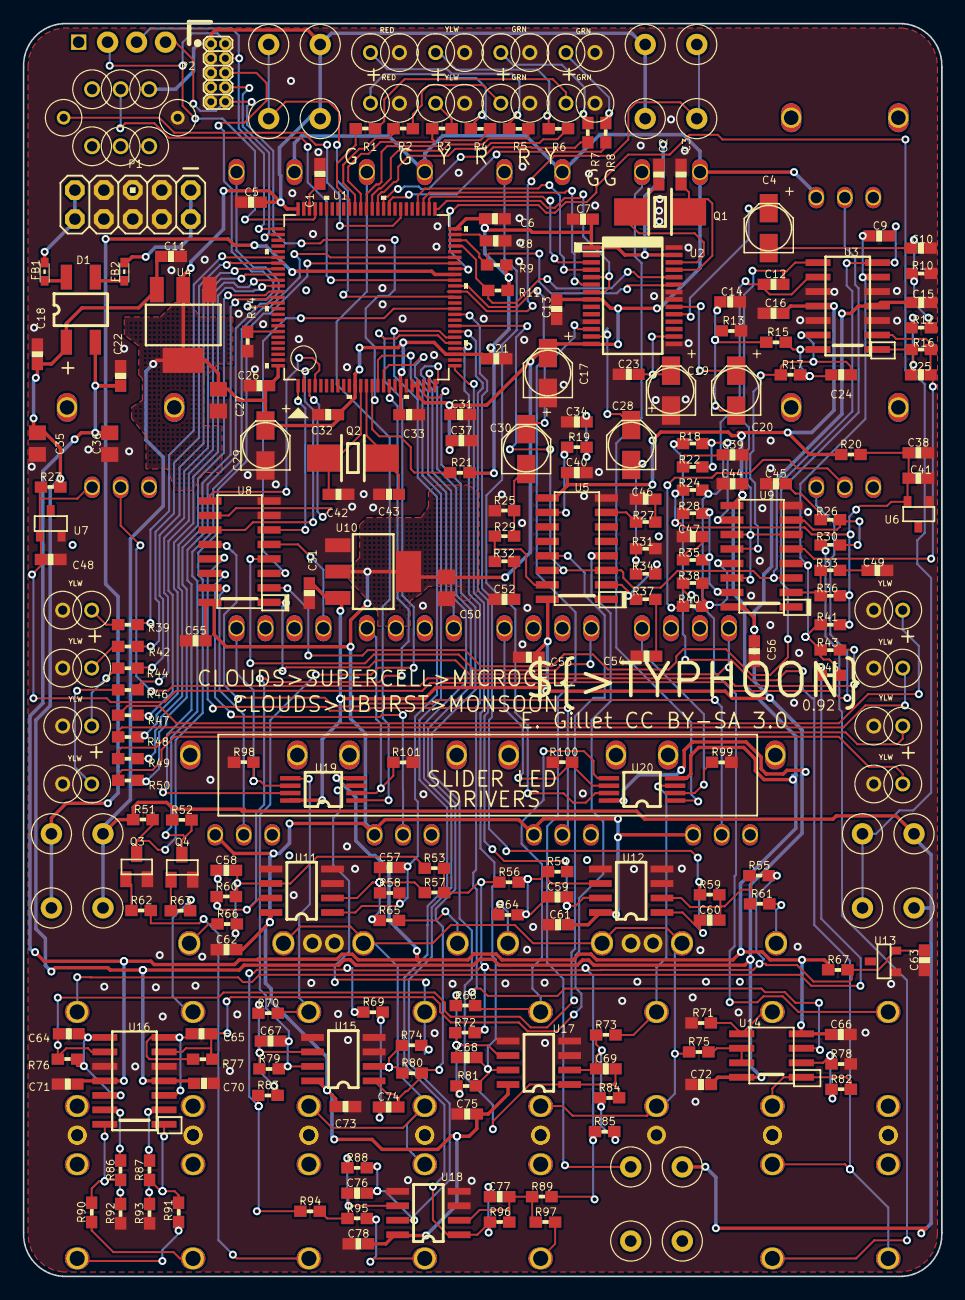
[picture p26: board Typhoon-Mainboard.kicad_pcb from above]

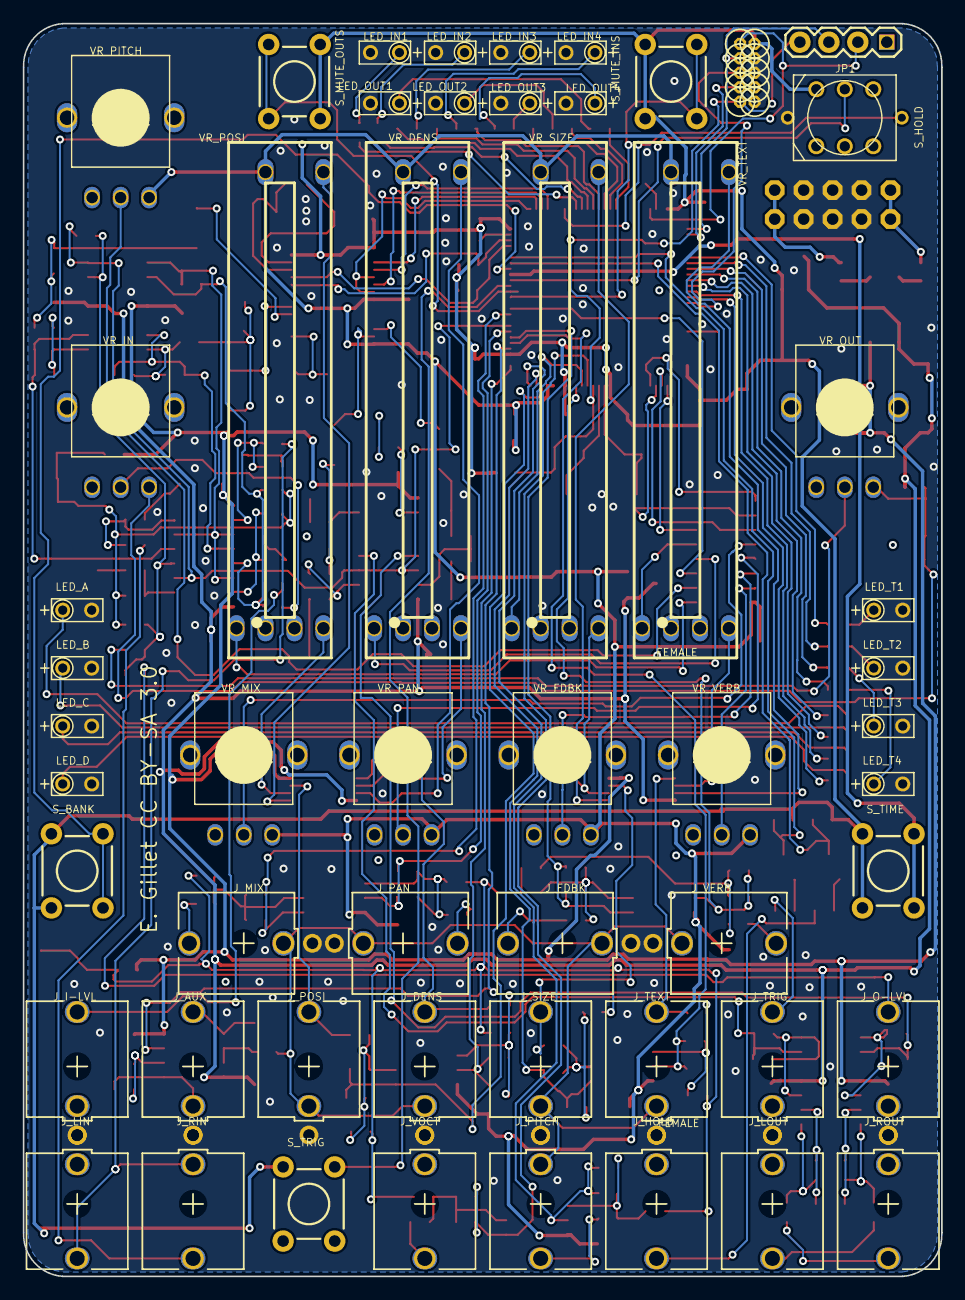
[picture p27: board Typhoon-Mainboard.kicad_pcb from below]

Board: 2 copper layers, 80.5 x 109.9 mm, 261 parts (53 on the bottom side), 182 nets.

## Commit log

2025-09-09 Update typhoon_BOM.csv
    Changed LEDs to 2mm
    [typhoon_BOM.csv]
2026-08-30 Delete Typhoon Build JLC/Front Panel Files - JLCPCB OK/Typhoon-Frontpanel-v1.1.zip
    Bad text issue from the original source 1234 ABCD are switched
2026-08-30 Delete Typhoon Build JLC/Front Panel Files - JLCPCB OK/Typhoon-Frontpanel-v1.3 (larger tactile switch button).zip
    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

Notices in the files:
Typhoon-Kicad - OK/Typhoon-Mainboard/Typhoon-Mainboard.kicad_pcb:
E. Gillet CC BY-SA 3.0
